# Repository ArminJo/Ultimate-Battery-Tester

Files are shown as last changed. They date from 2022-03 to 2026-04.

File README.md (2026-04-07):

<div align = center>

# Ultimate-Battery-Tester
Program for measuring the ESR (equivalent series resistance) of a battery and printing a graph of the values at discharge.


 &nbsp; &nbsp;

 &nbsp; &nbsp;

 &nbsp; &nbsp;

 &nbsp; &nbsp;

<br/>
<br/>
Stand With Ukraine (https://stand-with-ukraine.pp.ua)

</div>

#### If you find this library useful, please give it a star.

&#x1F30E; [Google Translate](https://translate.google.com/translate?sl=en&u=https://github.com/ArminJo/Ultimate-Battery-Tester)

<br/>

# Table of contents
- [Features](https://github.com/ArminJo/Ultimate-Battery-Tester?tab=readme-ov-file#features)
- [Li-Ion battery capacity](https://github.com/ArminJo/Ultimate-Battery-Tester?tab=readme-ov-file#li-ion-battery-capacity)
- [Battery ESR](https://github.com/ArminJo/Ultimate-Battery-Tester?tab=readme-ov-file#battery-esr)
- [Principle of operation](https://github.com/ArminJo/Ultimate-Battery-Tester?tab=readme-ov-file#principle-of-operation)
- [Measurement of battery packs with external series load resistor](https://github.com/ArminJo/Ultimate-Battery-Tester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)
- [Logger function](https://github.com/ArminJo/Ultimate-Battery-Tester?tab=readme-ov-file#logger-function)
- [Sample screenshots](https://github.com/ArminJo/Ultimate-Battery-Tester?tab=readme-ov-file#sample-screenshots)
- [Sample Arduino 1.89 IDE plots](https://github.com/ArminJo/Ultimate-Battery-Tester?tab=readme-ov-file#sample-arduino-189-ide-plots)
- [Compile with the Arduino IDE](https://github.com/ArminJo/Ultimate-Battery-Tester?tab=readme-ov-file#compile-with-the-arduino-ide)
- [Pictures](https://github.com/ArminJo/Ultimate-Battery-Tester?tab=readme-ov-file#pictures)
- [Schematics](https://github.com/ArminJo/Ultimate-Battery-Tester?tab=readme-ov-file#schematics)
- [Special pin usage](https://github.com/ArminJo/Ultimate-Battery-Tester?tab=readme-ov-file#special-pin-usage)
- [Examples on Wokwi](https://github.com/ArminJo/Ultimate-Battery-Tester?tab=readme-ov-file#examples-on-wokwi)
- [Modes of measurement](https://github.com/ArminJo/Ultimate-Battery-Tester?tab=readme-ov-file#modes-of-measurement)
   * [Mode Setup](https://github.com/ArminJo/Ultimate-Battery-Tester?tab=readme-ov-file#mode-setup)
   * [Stop and Start again](https://github.com/ArminJo/Ultimate-Battery-Tester?tab=readme-ov-file#stop-and-start-again)
   * [Mode DetectingBattery](https://github.com/ArminJo/Ultimate-Battery-Tester?tab=readme-ov-file#mode-detectingbattery)
   * [Mode InitialESRMeasurement](https://github.com/ArminJo/Ultimate-Battery-Tester?tab=readme-ov-file#mode-initialesrmeasurement)
   * [Mode StoreToEEPROM](https://github.com/ArminJo/Ultimate-Battery-Tester?tab=readme-ov-file#mode-storetoeeprom)
   * [Mode Stopped](https://github.com/ArminJo/Ultimate-Battery-Tester?tab=readme-ov-file#mode-stopped)
   * [Cutoff display](https://github.com/ArminJo/Ultimate-Battery-Tester?tab=readme-ov-file#cutoff-display)
- [Revision History](https://github.com/ArminJo/Ultimate-Battery-Tester?tab=readme-ov-file#revision-history)

<br/>

# Features
- **Measurement of the ESR (equivalent series resistance) of the battery.** This is an indicator of the health of the battery.
- **Storing of voltage, current and ESR graph for up to 22 hours as well as capacity in EEPROM** while discharging.
- The **stored and displayed voltage is the "no load" voltage**, and is therefore **independent of the ESR**, as is the capacity.
- Current measurement values or complete EEPROM stored measurement graph can be displayed with **Arduino Plotter**.
- Easy **continuing of interrupted discharge measurements**.
- Display of ESR, voltage, current and capacity on a **1602 LCD**.
- Display of values and the **discharge graph on a tablet or mobile** running the [BlueDisplay](https://play.google.com/store/apps/details?id=de.joachimsmeyer.android.bluedisplay) app.
- Computing of **"Standard" capacity** between NominalFullVoltageMillivolt and SwitchOffVoltageMillivoltHigh to enable better comparison of capacity measurements.
- Selectable cutoff voltage `Standard`, `Low` and `Zero` (for research). E.g. for Li-ion they are 4.3 V, 3.0 V and 0.18 V.
- Support of **2 different load resistors** for different battery voltages to keep current below 600 mA.
- Support of **4 automatically selected voltage ranges** 2.2 V, 4.4 V, 17.6 V and 64.9 V. This results in a high resolution ranging from 2.1 mV to 63 mV.
- Support of **external series load resistor** e.g. for measuring of battery packs.
- **Logger mode (voltage + current)** for charting external charger or similar devices.
- In case the ESR is changing a lot, the **load voltage** can be determined by looking at the current, because the load resistance is constant.

<br/>

# Li-Ion battery capacity
For Li-Ion the capacity is specified for discharge from **4.2 V to 3.0 V** as in [CGR18650CG Datasheet](https://github.com/ArminJo/Ultimate-Battery-Tester/blob/master/CGR18650CG-Panasonic.pdf)
or to **2.75 V** as in [ICR18650-26A Datasheet](https://github.com/ArminJo/Ultimate-Battery-Tester/blob/master/ICR18650-26A_Samsung.pdf) or even to **2.5 V**.<br/>
The **UltimateBatteryTester has a cut-off voltage of 3.4 V** for Li-Ion to treat the cells with care.<br/>
This results in a reduced capacity displayed by approximately the factor 0.85 (1.18), e.g. a Li-Ion cell with nominal capacity of 2150 mAh at 3 V EOD (End Of Discharge) is measured as 1830 mAh at 3.5 V EOD.<br/>
The cut off voltage can be changed to low values by connecting pin 11 to ground. See [here](https://github.com/ArminJo/Ultimate-Battery-Tester?tab=readme-ov-file#special-pin-usage).

<br/>

# Battery ESR
The internal resistance is an indicator of the health of the cell. E.g. if a NiMH cell has an ESR of **1 &ohm;**, it delivers **only 1 volt at a current of 200 mA** instead of 1.2 V, which may be to low for the circuit to work properly.<br/>
ESR values for NiMH can go down to excellent 0.05 &ohm;.<br/>
Typical ESR value for a 18650 Li-Ion cell is 0.05 &ohm;.

It seems that the **dynamic ESR** measured by devices like **YR1035+** is around half as much as the **static ESR** measured by this program.
This was suprising for me, since I expected only a fixed offset, because of connection imperfections.<br/>
But this **static ESR gives you a better impression of the voltage loss at a given static current**.

<br/>

# Principle of operation
The battery type is detected by a fixed mapping of voltage to type in `BatteryTypeInfoArray[]`.
While the Mosfet is switched on, the voltage at the 2 &ohm; shunt resistor is measured to get the current. The voltage at the battery terminal is measured to get the voltage under load.<br/>
Every second, the Mosfet is deactivated for 10 ms or 100 ms (depending on battery type), the "no load" voltage at the battery terminal is measured and the Mosfet is switched on again.<br/>
The formula for ESR is: **(noLoadVoltage - loadVoltage) / loadCurrent**.<br/>
Please keep in mind, that the **maximum current which can be measured with the 2 &ohm; shunt resistor is 545 mA**.<br/>
The internal LED is active for the time the load is detached. This results in a 1 second blinking.

Every minute, current data is stored/appended to EEPROM. **The complete data is printed in Arduino Plotter format at each reboot**.
So it is possible to interrupt the measurement or switch it off after the measurement is finished, without loosing data.
More details can be found [below](https://github.com/ArminJo/Ultimate-Battery-Tester?tab=readme-ov-file#modes-of-measurement).

If `#define SUPPORT_BLUEDISPLAY_CHART` is activated, values and the discharge graph are printed on a tablet or mobile running the [BlueDisplay](https://play.google.com/store/apps/details?id=de.joachimsmeyer.android.bluedisplay) app.<br/>
The new version of the app also supports a USB OTG connection. This eliminates the need for an additional Bluetooth module.

<br/>

# Measurement of battery packs with external series load resistor
Battery packs up to 64.9 volt (15s) can also be measured.
**However, it is important to keep the current below 545 mA**, as this is the maximum allowed for current measurement with the 2 &ohm; shunt resistor.<br/>
This can be achieved by **adding an extra resistor in series with the built-in 12 &ohm; resistor**.<br/>
The voltage must still be measured directly at the battery terminal.
For this I use a distinct cable for voltage measurement, connected to the battery’s positive lead.<br/>
No further modifications are required.

<br/>

# Logger function
Connecting pin 10 to ground enables Logger mode after startup. In this mode, voltage is measured at the same pin used for Battery mode.
For current measurement, Logger mode uses a separate external shunt connected to pin A4.<br/>
To minimize interference with the circuit under test, this shunt is typically smaller than the one used in Battery mode. 
Its resistance is defined by `LOGGER_SHUNT_RESISTOR_MILLIOHM` (e.g., 200 for 0.2 &ohm;).<br/>
The measurement stops when the current falls below a specified fraction of the initial current. 
Available thresholds are 50%, 25%, or 12.5%, with 12.5% as the default. 
This default is particularly useful for logging charging circuits that gradually reduce current toward the end of the charge cycle.

<br/>

# Sample screenshots
This screenshots are from an 1200x800 tablet running the [BlueDisplay](https://github.com/ArminJo/Arduino-BlueDisplay) app.
The Arduino is connected to the tablet via **OSB OTG** or a **Bluetooth module** like HC-05, see [here](https://github.com/ArminJo/Arduino-BlueDisplay?tab=readme-ov-file#bluedisplayblink).

|  |  |
|-|-|
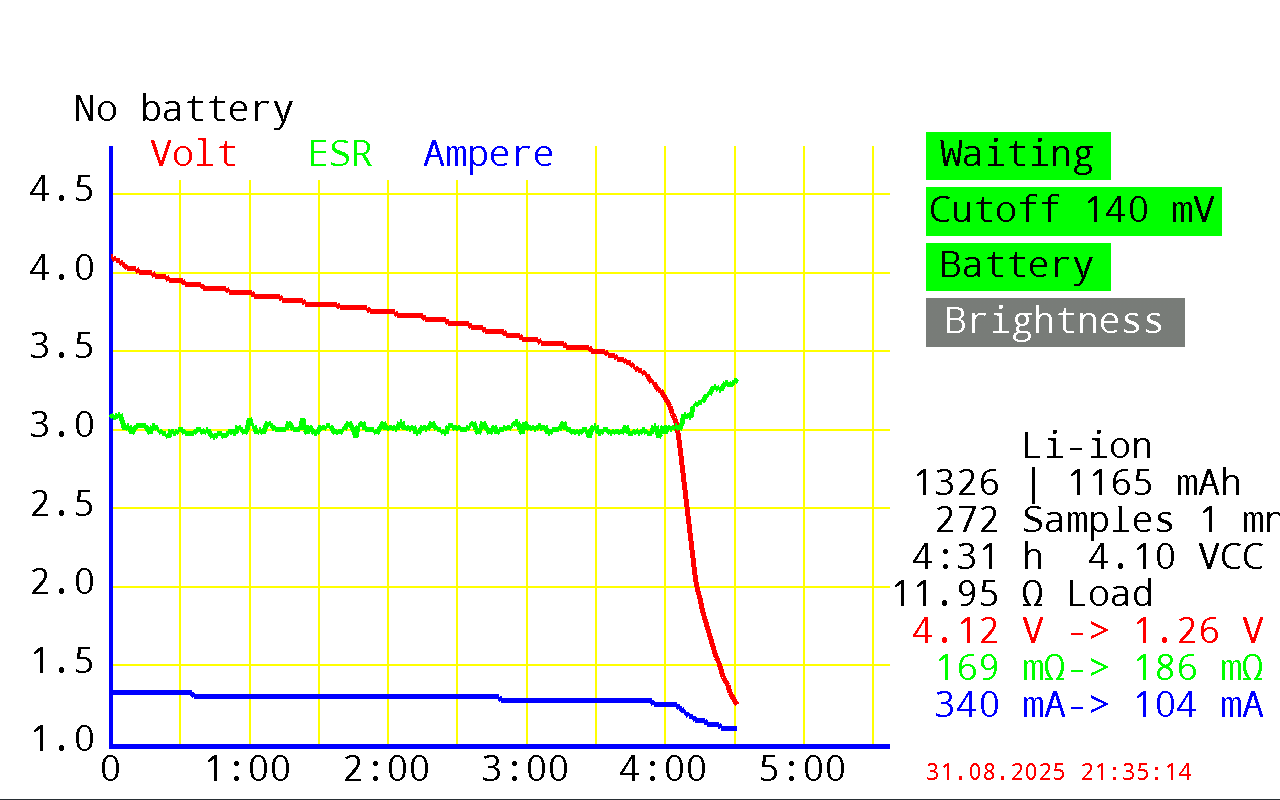
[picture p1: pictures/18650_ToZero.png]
Li-ion
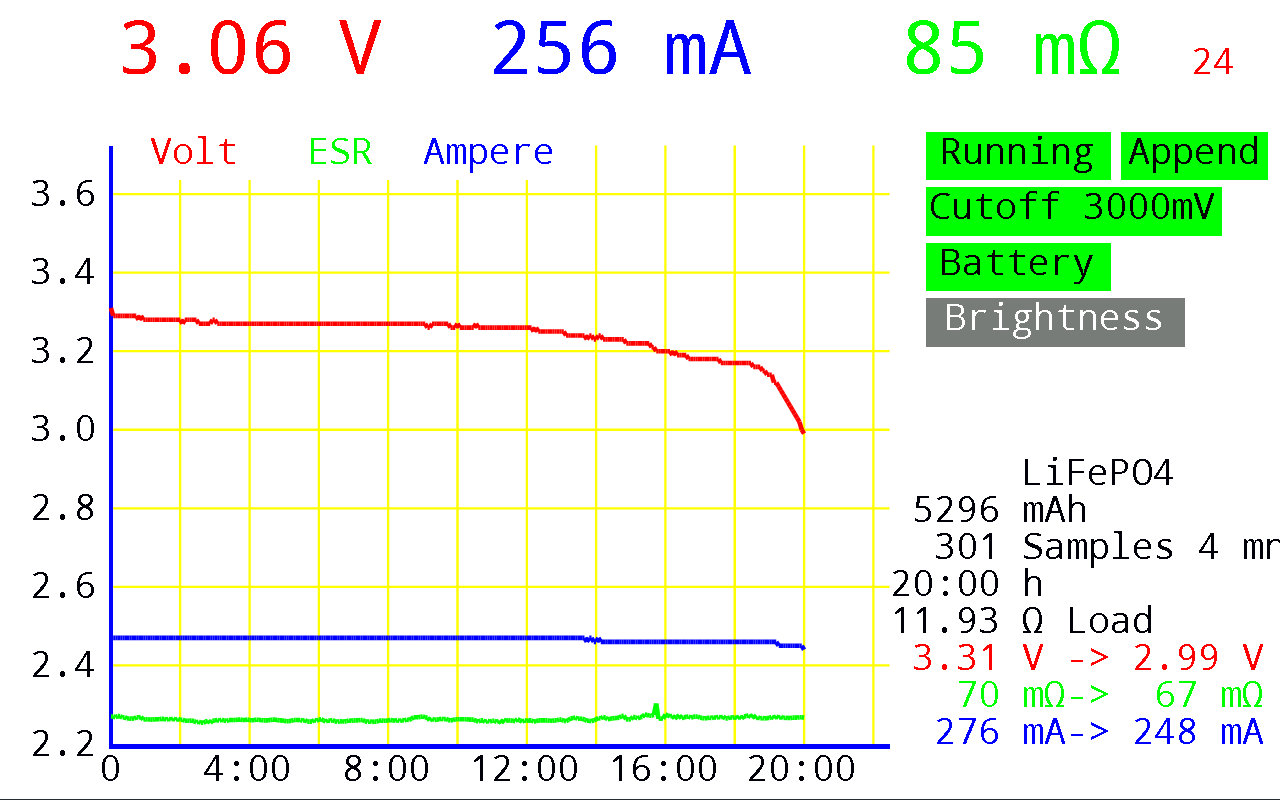
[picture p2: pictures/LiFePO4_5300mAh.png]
LiFePO4_5300mAh
|  |  |
| Used 18650 Li-ion battery. | LiFePO4 battery with 5300 mAh.  |
| | |
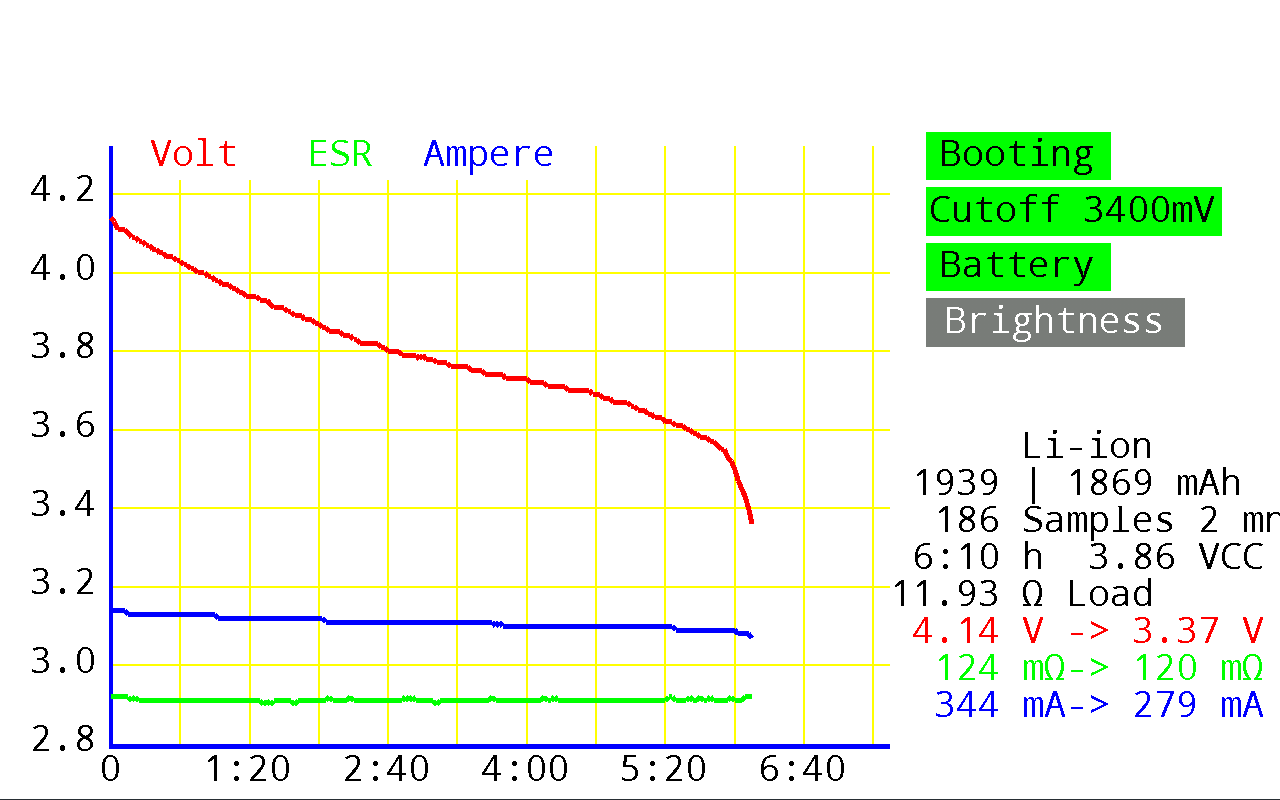
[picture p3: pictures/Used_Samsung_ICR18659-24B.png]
Used_Samsung_ICR18659-24B
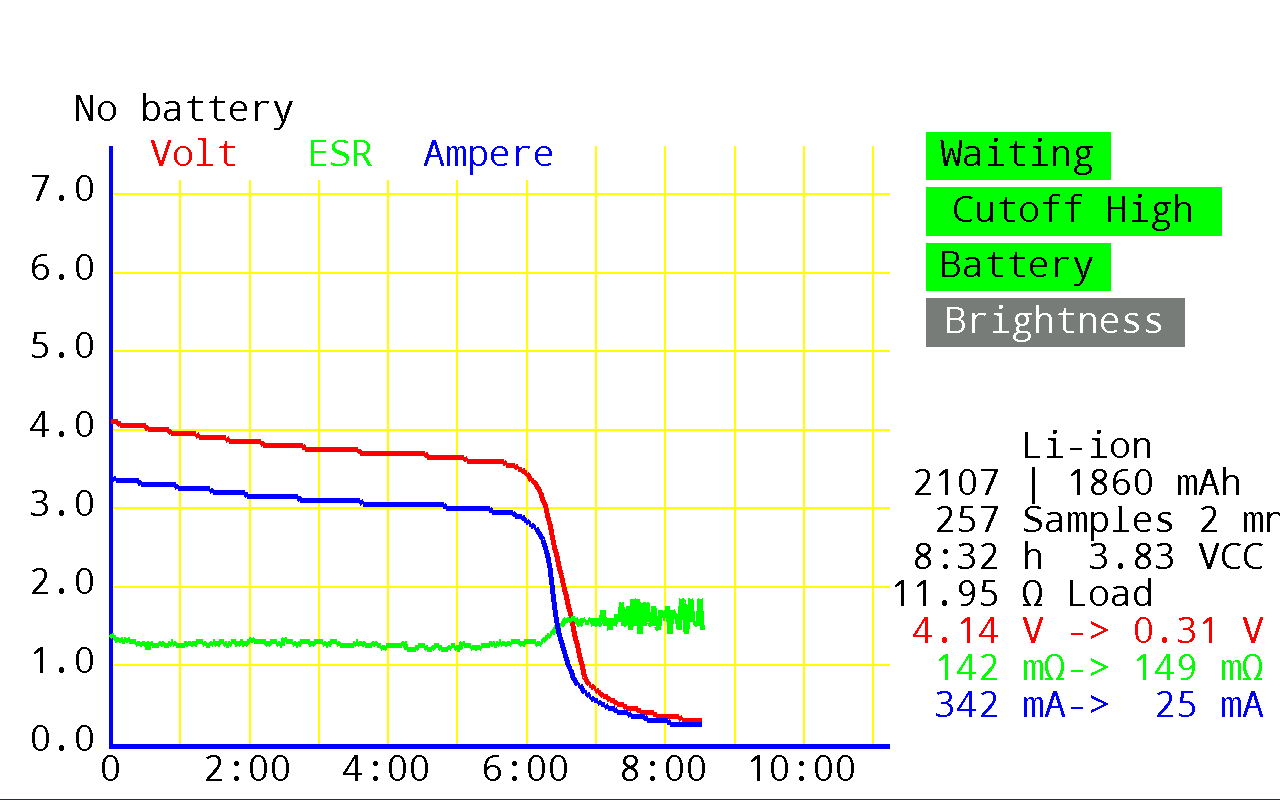
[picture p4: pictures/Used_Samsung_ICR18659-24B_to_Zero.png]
Used_Samsung_ICR18659-24B_to_Zero
|  |  |
| Used Samsung ICR18659 24B with 1100 mAh. | The same Samsung ICR18659 24B **accidentally discharged to almost zero**. Here you can see the small capacity below 3.4 V. After directly recharging with 10 mA until 2.8 V and then with 30 mA to 3.5 V the capacity and ESR were like before, which I did not expect :-). |
| | |
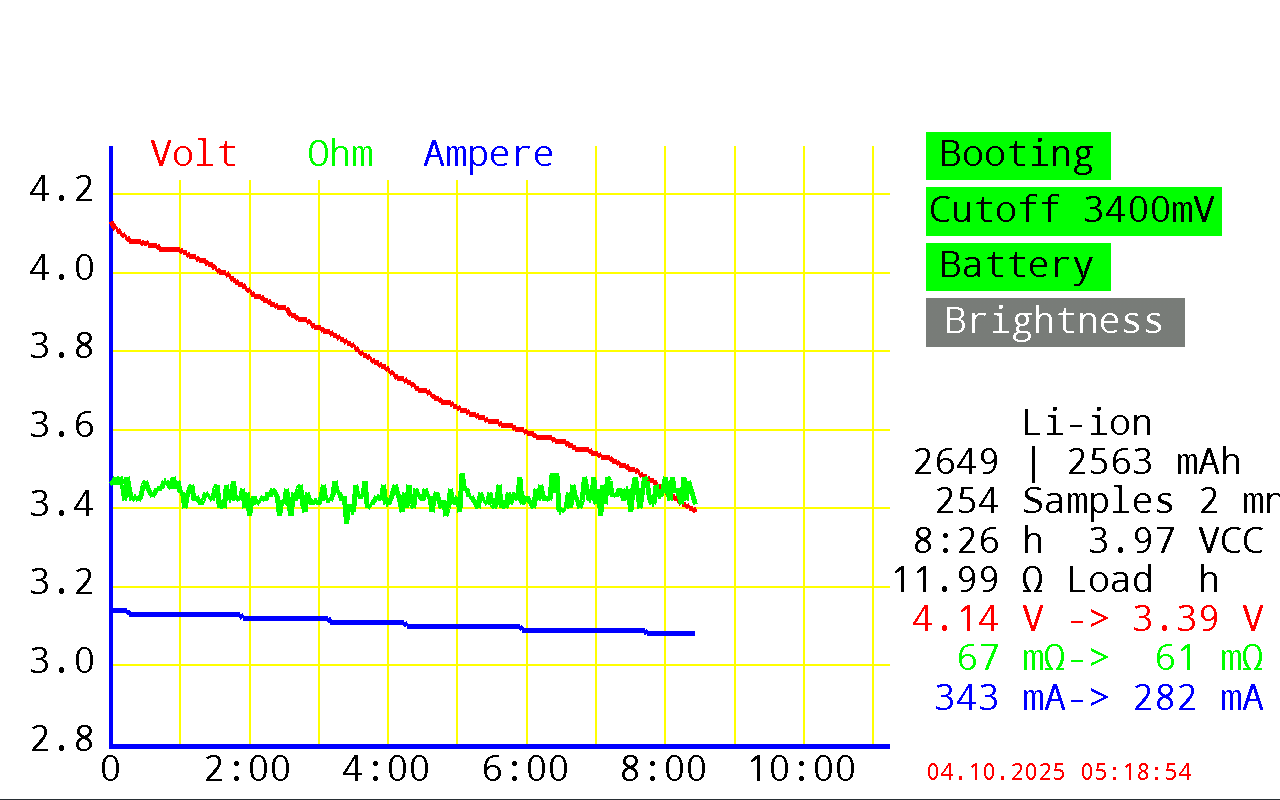
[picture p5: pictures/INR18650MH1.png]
INR18650MH1
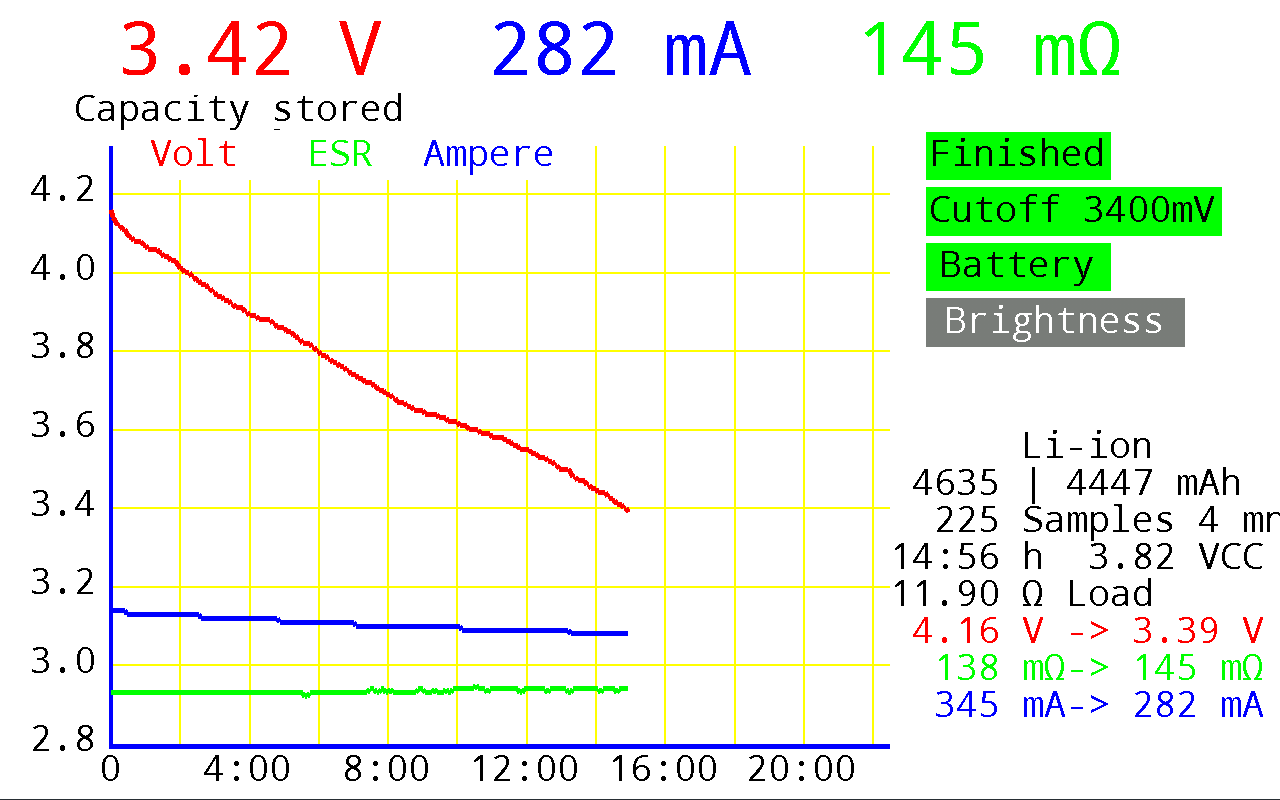
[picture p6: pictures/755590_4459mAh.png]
755590_4459mAh
|  |  |
| A LG INR18650MH1 cell salvaged from a scooter battery. |  A new 755590 pouch cell with 4459mAh and an ESR of 0.14 &ohm;, maybe because of the protection circuit. |
| | |
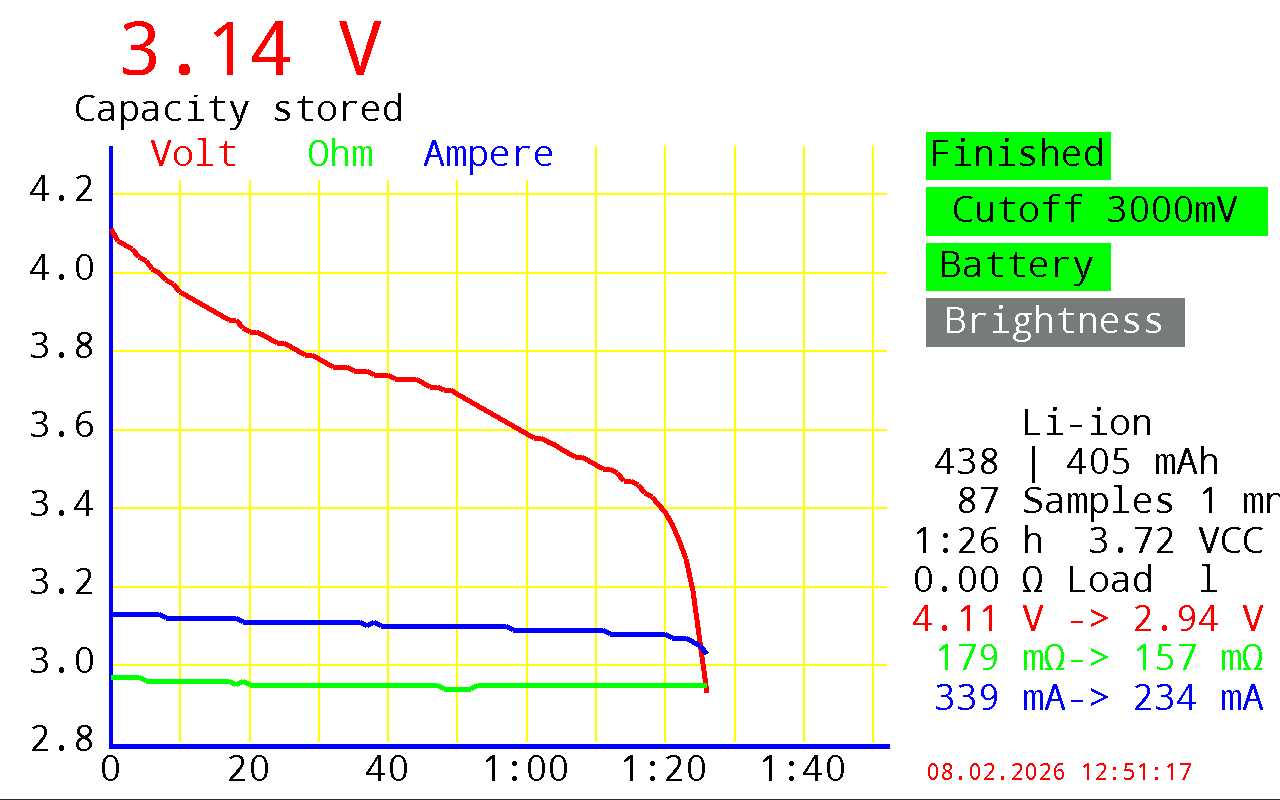
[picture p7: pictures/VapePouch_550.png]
VapePouch
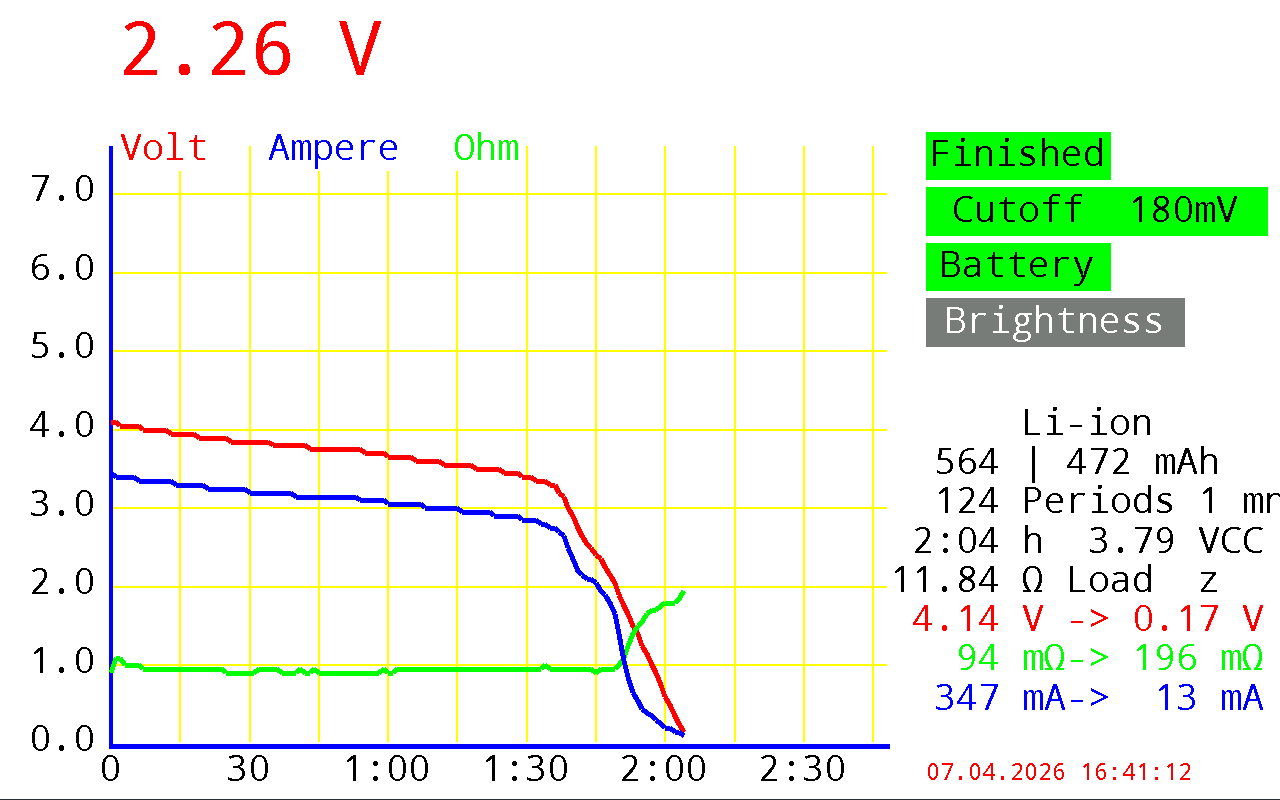
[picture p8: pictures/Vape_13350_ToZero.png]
VapeRound
|  |  |
| A 550 mAh pouch cell salvaged from a vape. | A 13350  450 mAh? cell salvaged from a vape. |
| | |
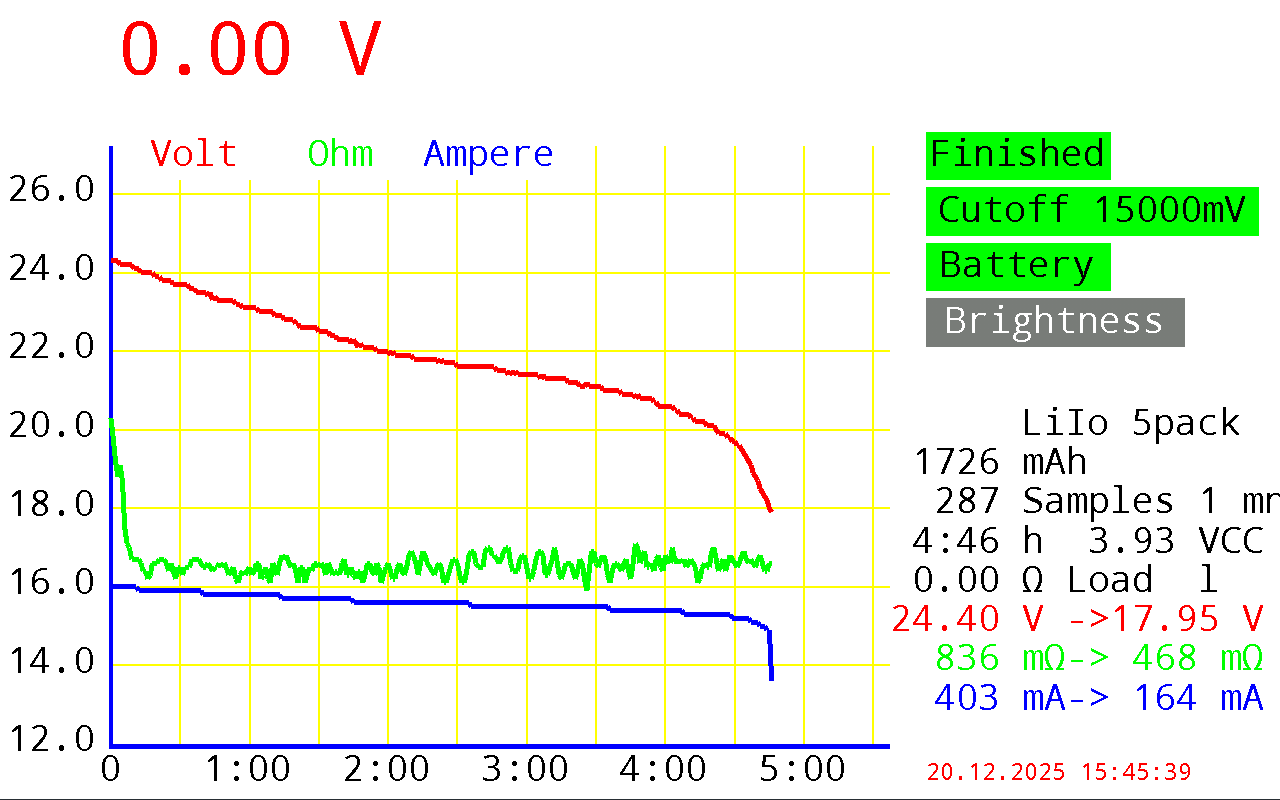
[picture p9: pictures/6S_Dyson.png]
Dyson pack
|  | |
| A 6s Dyson battery pack. | |

<br/>

# Sample Arduino 1.89 IDE plots
The plots are created with the Arduino 1.x Serial Plotter. The Arduino 2.x Serial Plotter is not as powerful and uses a different data format.

Plot for **2 parallel 18660 Li-Ion cells**.<br/>
The first capacity value is the "standard" capacity measured from the first peak at standard full voltage 4100 mV to the second peak, the cutoff "high" voltage at 3400 mV.<br/>
The peaks, which are 50 mV added to the measured value, are artificially generated for easy recognition of the capacity range.<br/>
The second peak is always suppressed for graphs with discharge to "high", because the end of this graph is by definition the end of the standard capacity range.<br/>
The second capacity value is the total capacity measured in this graph.<br/>
**The displayed voltage is the "no load" voltage**, to be independent of the current load resistor.
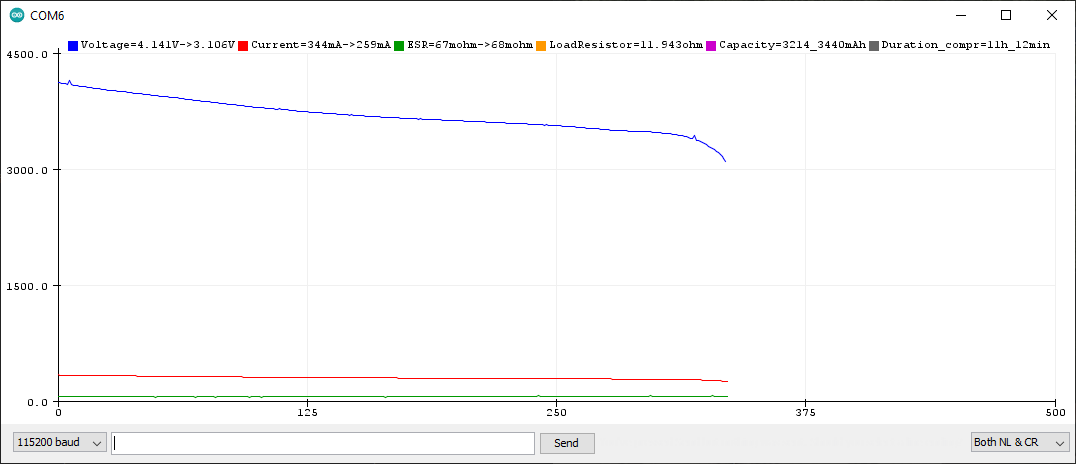
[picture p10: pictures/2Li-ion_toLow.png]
2Li-ion_toLow


Plot a **worn out single Li-ion cell** with increased ESR and a more flat curve at 3.4 V.
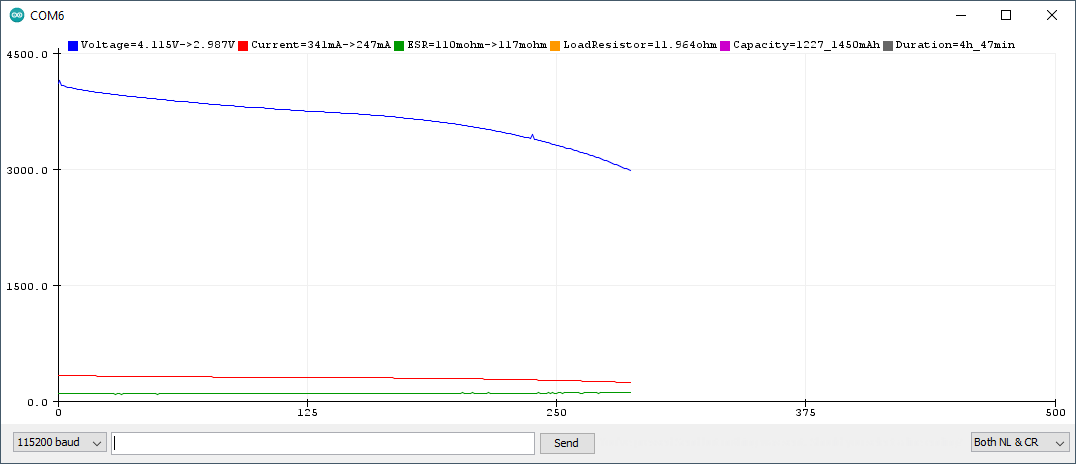
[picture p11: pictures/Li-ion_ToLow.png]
Li-ion_toLow


Plot for a **NiMH cell** with 55 m&ohm; ESR.
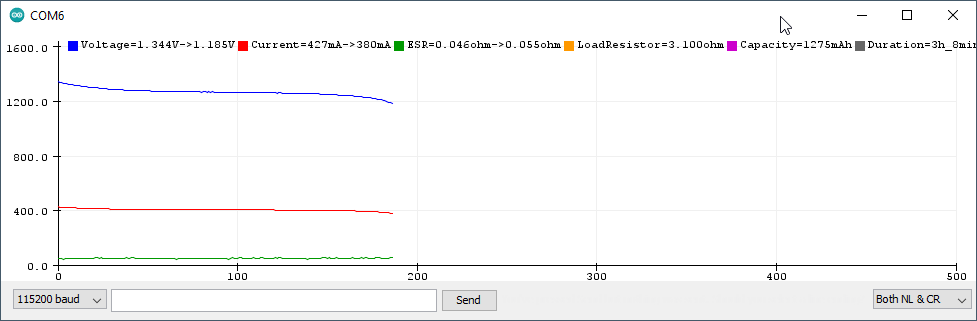
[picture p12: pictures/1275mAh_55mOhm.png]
870mAh_120mOhm


Plot of a NiMh battery sold as 4/5AA 1800mAh Ni-Mh showing only 960 mAh.
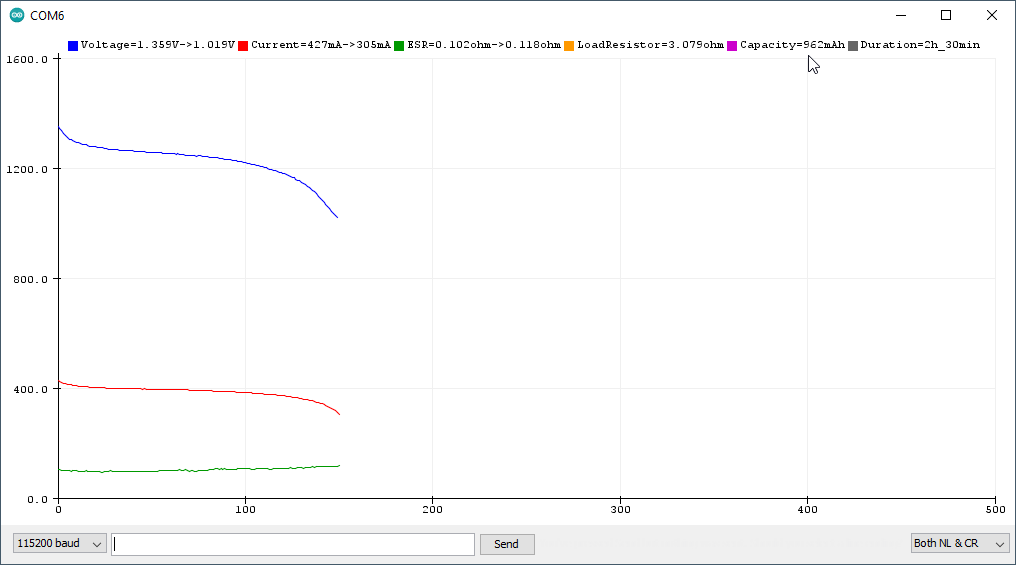
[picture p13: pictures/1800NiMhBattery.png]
1800mAh
 

<br/>

# Compile with the Arduino IDE
Download and extract the repository. In the Arduino IDE open the sketch with File -> Open... and select the UltimateBatteryTester folder.

As the program size is at around 100%, you need to burn the UNO bootloader on the Nano before loading the program onto the Nano.

# Pictures

| Overview with distinct voltage measurement cable (thin red one) to enable additional series resistors for battery packs | Top View |
|-|-|
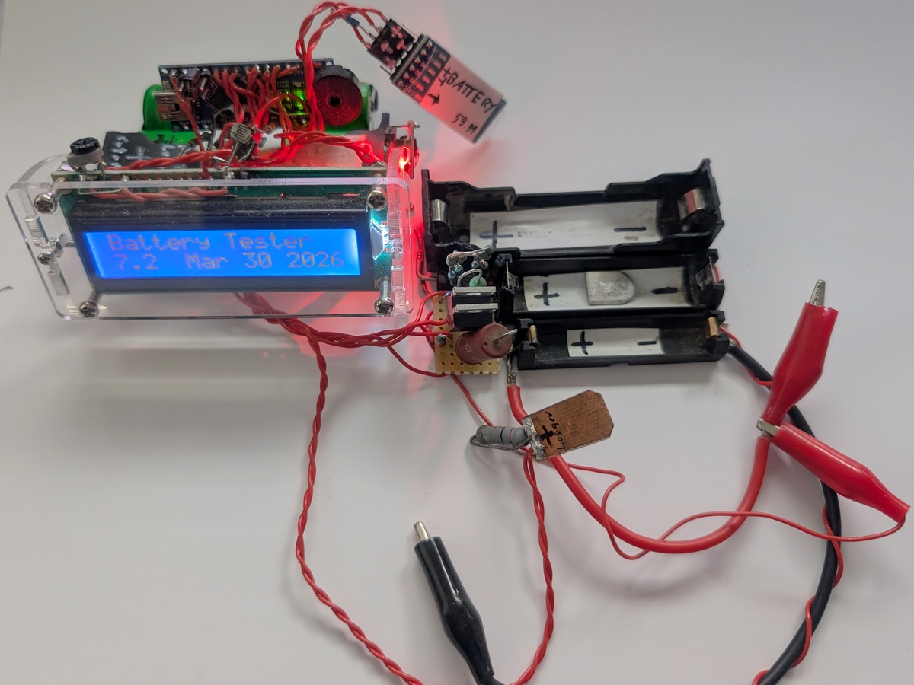
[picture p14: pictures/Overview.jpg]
Overview
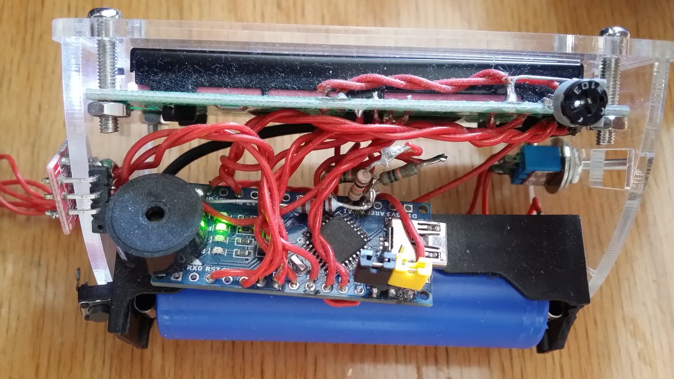
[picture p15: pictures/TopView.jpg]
Top View
|  |  |
| Battery holder top view  | Reset and application sensor button |
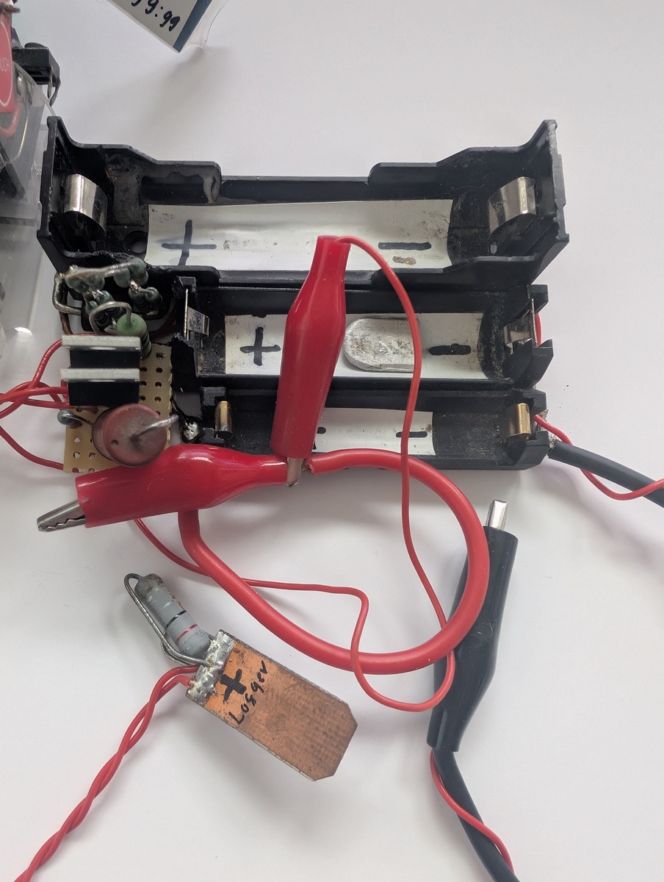
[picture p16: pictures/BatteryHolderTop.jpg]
BatteryHolderTop
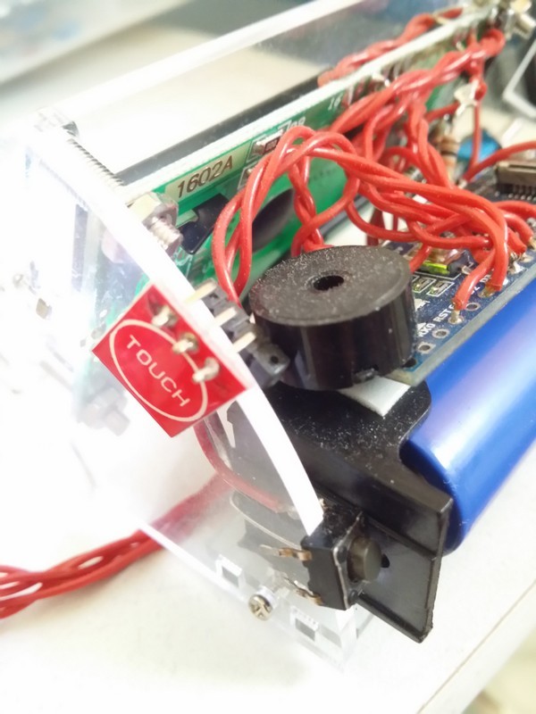
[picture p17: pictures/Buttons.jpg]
Reset and application sensor button
|  |  |
| Battery holder bottom view | MosFets |
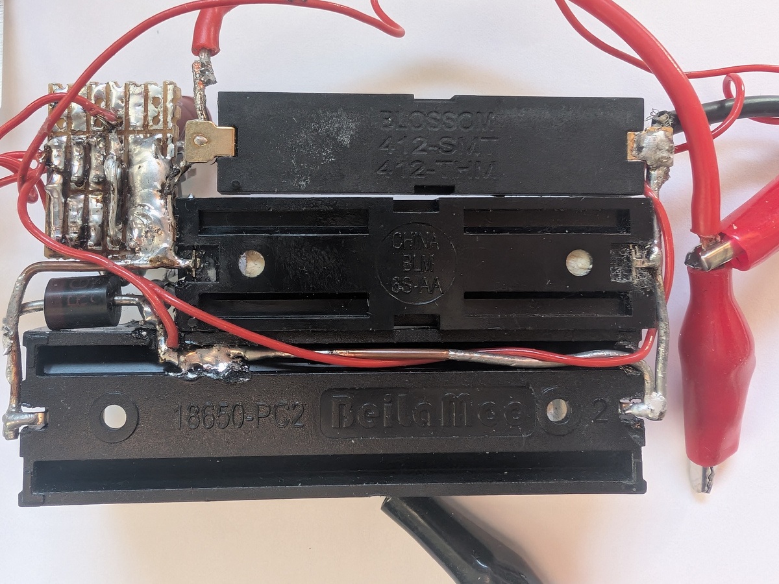
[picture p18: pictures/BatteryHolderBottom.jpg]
Battery holder bottom view
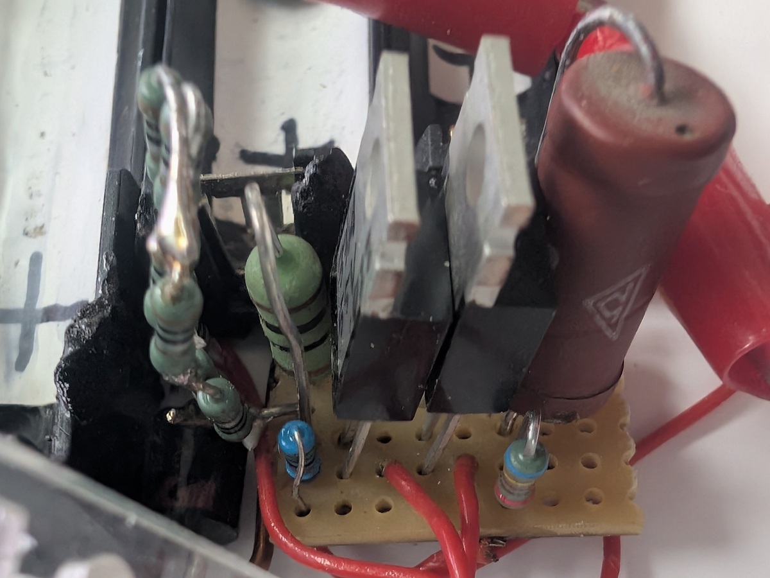
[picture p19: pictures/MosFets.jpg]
|  |  |

# Schematics
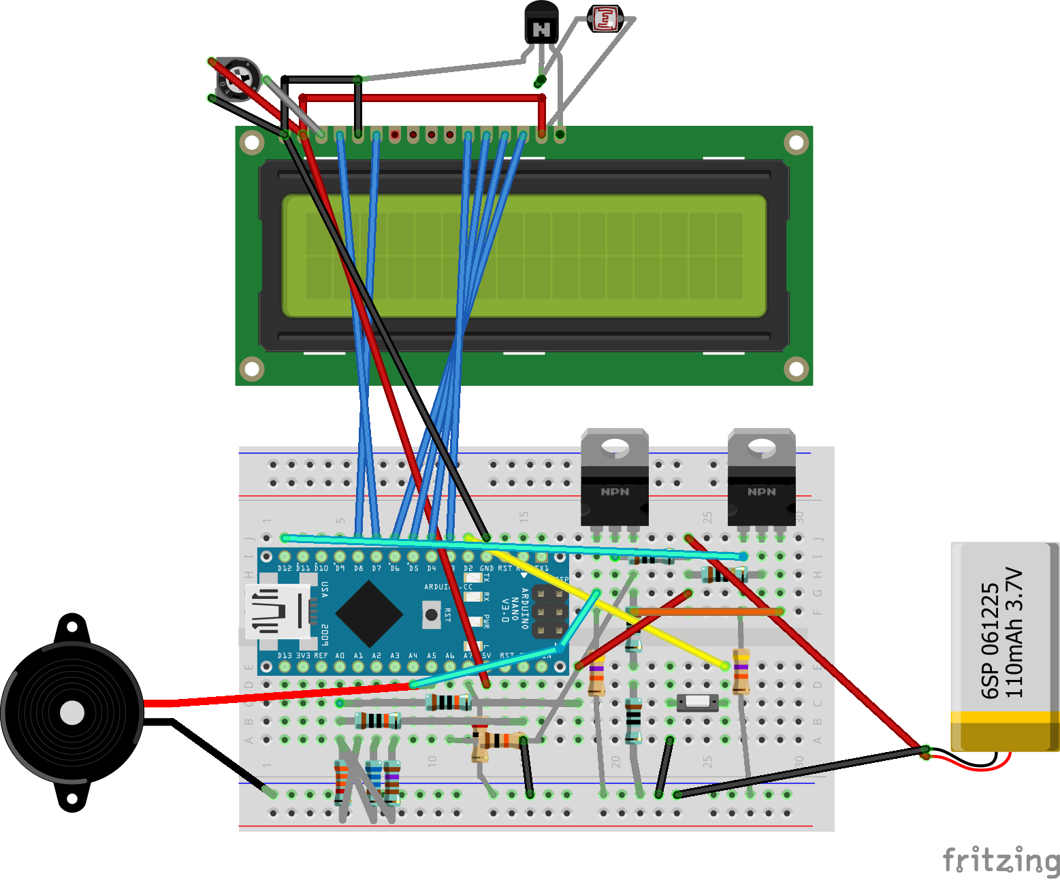
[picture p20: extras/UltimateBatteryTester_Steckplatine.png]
Fritzing board

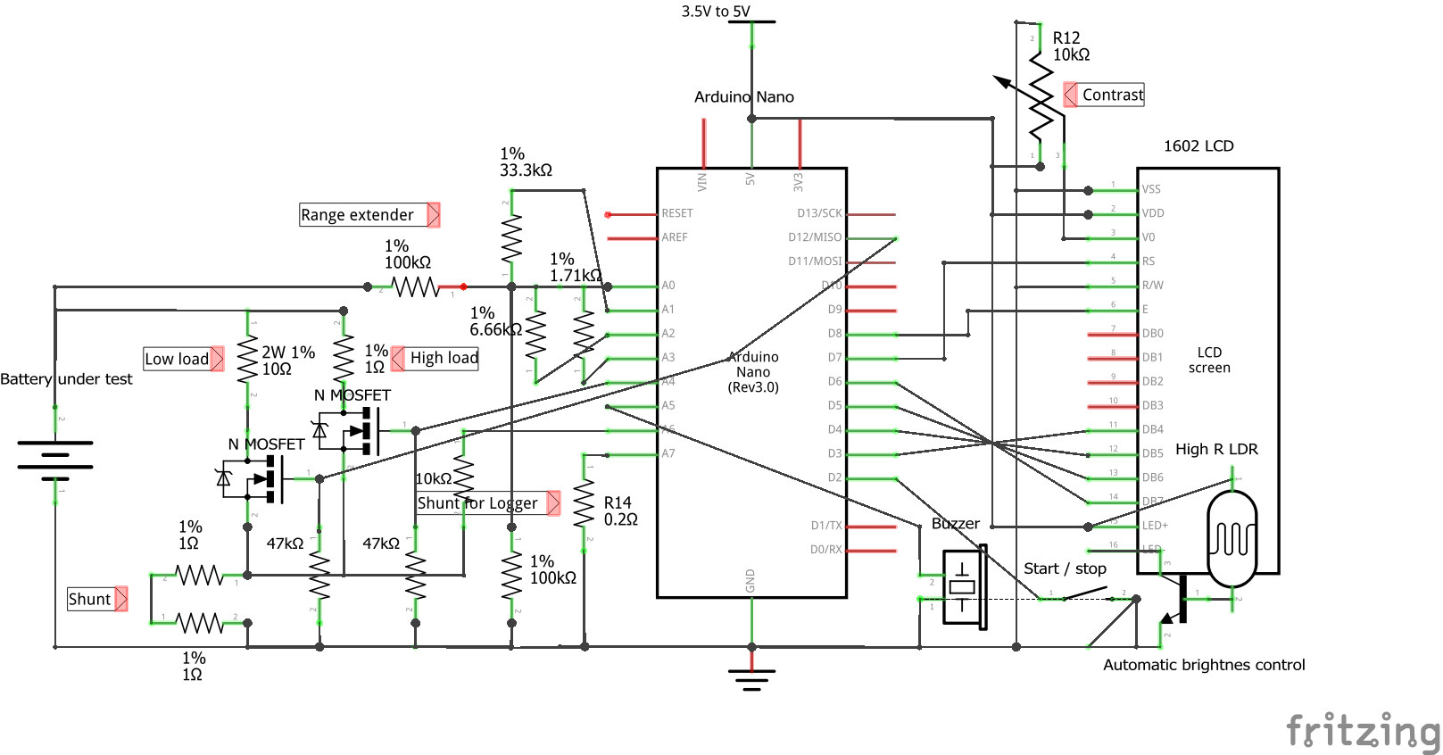
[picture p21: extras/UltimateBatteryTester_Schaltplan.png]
Fritzing schematics


# Special pin usage
If **pin 9** is connected to ground, verbose output for Arduino Serial Monitor is disabled. This verbose output is not suitable for Arduino Plotter.<br/>
If **pin 10** is connected to ground, **logger mode** is entered. I.e. current is measured at the shunt at channel 4 / A4 and voltage still at channel 0 / pin A0.<br/>
If **pin 11** is connected to ground, `CUTOFF_LEVEL_LOW` is taken as startup default if no battery is inserted at startup, "cut off is low" is displayed and discharge ends at a lower voltage. E.g. Li-ion discharge ends at 3000 mV instead of 3500 mV.

# Examples on Wokwi
The screenshots below are taken from this [Wokwi example](https://wokwi.com/projects/381051341790948353).

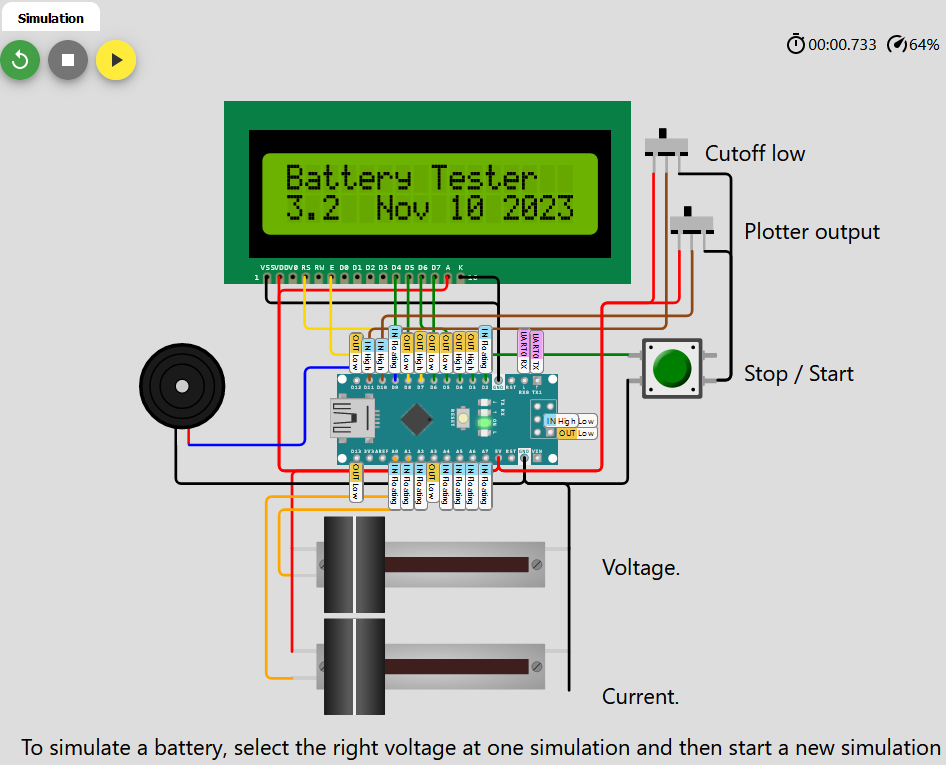
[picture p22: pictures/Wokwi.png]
Wokwi


# Modes of measurement
After reset the tester starts with mode Setup:

## Mode Setup
After boot, the tester displays its name and version and date for 2 seconds.

BatteryTester

The message `No plotter out` is displayed in the second row for 2 seconds.
If pin `PIN_ONLY_PLOTTER_OUTPUT` (pin 10) is held low, then the message `Only plotter out` is displayed.

NoPlotterOut
OnlyPlotterOut

Then it prints the data read from EEPROM to serial monitor and displays ESR and capacity.
The Arduino supply voltage (VCC) together with the message `Stored data` is displayed in the first row for 2 seconds.<br/>
The character `h` or `l` or `z` shows the cutoff voltage of the stored data.

StoredData

Then the message `cutoff high` or `low`  and the cutoff voltage is displayed in the first row for 2 seconds.<br/>
If battery is still inserted, it reflects the cutoff voltage of the stored data, to enable easy **continuing an interrupted measurement**.<br/>
If no battery is inserted, this cutoff message reflects the state of the pin `PIN_DISCHARGE_TO_LOW`.

CutoffHigh
CutoffLow

After this, **mode is switched to DetectingBattery**.<br/>

## Stop and Start again
A double press during 0.4 seconds always displays `Stop measurement` for 2 seconds and then **mode is switched to Stopped**.<br/>
Another press will start again.
`Stopped B` means stopped by **button** press, `Stopped D` means stopped by button **double** press, `Stopped F` means stopped by EEPROM **full**,
`Stopped -` means stopped by reaching the cutoff voltage and `Stopped U` means stopped by VCC undervoltage.

StopMeasurement
Stopped

StartAgain

## Mode DetectingBattery
If no battery is inserted, the Arduino supply voltage (VCC) together with the message `No batt.` is displayed in the first row until a battery is inserted.<br/>

NoBatt

By pressing the stop button, you can toggle cutoff voltage between high, low and zero (50 mV).

NoBatt
NoBatt
NoBatt

If a battery is inserted, you see e.g.

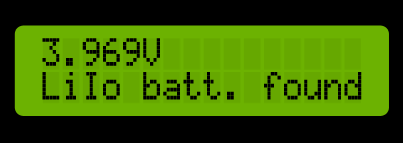
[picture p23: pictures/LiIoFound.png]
LiIoFound


for 2 seconds.
Then the messages `dbl press = stop`,  and `Press button to append to EEPROM` are displayed for 2 seconds each, but only once after boot.

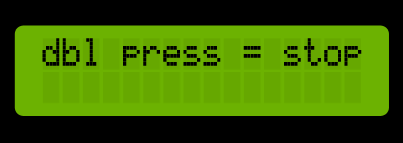
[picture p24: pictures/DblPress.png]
DblPress

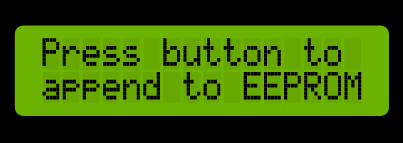
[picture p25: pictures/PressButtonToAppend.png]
PressButtonToAppend


After this, the mode is **switched to InitialESRMeasurement**.

## Mode InitialESRMeasurement
This mode lasts for 30 seconds before a new measurement is initiated and **mode is switched StoreToEEPROM**.<br/>
This 30 seconds can be used to quick check a battery, without overwriting the already stores values.<br/>
A button press during the 30 seconds **switches directly to mode StoreToEEPROM and appends to already stored EEPROM data**, instead of starting a new measurement.
This enables it to connect the tester to the Arduino Serial Plotter at any time in the measurement without loosing data already acquired.
Because connecting to the Serial Plotter always resets the tester, we must be able to avoid to start a fresh measurement after reset.

InitialESRMeasurement

In the first row the **no load voltage** of the battery, the **30 second countdown** and the **load current** is displayed.
In the second row the **ESR** and the **difference between the load and no load voltage**, used to compute the ESR, is displayed.<br/>
A value of **99.999 &ohm; indicates overflow** over the maximum value of 65.535 &ohm;.

## Mode StoreToEEPROM
- Every second, a sample is taken and displayed.
- Every 60 seconds the sample is stored.
- For the first 337 samples (5:37 hours) each 8 bit delta is stored to EEPROM.
- After 337 samples, all data are compressed by combining 2 samples and doubling the sample period This can be done multiple times.
- The number between the voltage and the current in the first row is the storage minute count and incremented at each storage.

Storing

If the **no load voltage drops below the cut off voltage** or the start/stop button is pressed, `Capacity stored` is displayed for 2 seconds,
the current capacity is written to EEPROM and **mode is switched to Stopped**.

CapacityStored

## Mode Stopped
The battery no load voltage is displayed in the first row. A stop melody is played and `Finished` is displayed **after reaching the cutoff voltage**.<br/>
`Stopped B` is displayed after manual stopping by button press.<br/>

Finished
Stopped by button single press

After another button press `Start again` is displayed and **mode is switched to DetectingBattery**.
StartAgain

## Cutoff display
If the state of the `PIN_DISCHARGE_TO_LOW` pin changes, the message `cutoff high` or `low`
and the according cutoff voltage is displayed in the first row for 2 seconds.

CutoffHigh
CutoffLow

# Revision History
### Version 7.2.0
- BatteryTypeInfoArray now in FLASH memory.

### Version 7.1.0
- Fixed bugs in ESR and load resistor computations.
- Fixed overflow bug relevant after 336 storage periods.
- Use period instead of sample for display.

### Version 7.0.0
- Changed analog pin assignments for two additional voltage ranges using internal reference.
- Fixed some bugs in logger mode.
- First tap on Brightness button only makes refresh.

### Version 6.0.0
- Improved logger handling.
- Improved chart scaling.
- Display of date and time for BlueDisplay mode. This requires 1304 bytes program memory and does not work for plain Arduino, because the "-mrelax" linker option is not set.
- Refactoring.
- Added battery specific zero value.

### Version 5.1.0
- Adaptive Chart data text size.
- Improved RunningState BDButton handling.

### Version 5.0.0
- Compression is now done by simply doubling the sampling period, which results in reducing the resolution from 336 of 168 samples directly after compression.
- Data and chart can be displayed on (old) tablets or mobile running the BlueDisplay app https://github.com/ArminJo/Arduino-BlueDisplay.
- Plotter pin logic does not depend any more on USB powering.
- Tested logger function with chart.

### Version 4.0.0
- Use capacity between NominalFullVoltageMillivolt and SwitchOffVoltageMillivoltHigh as standard capacity to enable better comparison.
- If powered by USB plotter pin logic is reversed, i.e. plotter output is enabled if NOT connected to ground.
- In state detecting battery, you can toggle cutoff voltage between high, low and zero (50 mV) with stop button.
- Fix bug for appending to compressed data.
- Support for storage period of 120 s.
- Synchronizing of LCD access for button handler, avoiding corrupted display content.
- Print improvements.
- Support for storage period of 120 s.
- Compression improved for rapidly descending voltage.
- Moving seldom used function of pin 10 to pin A5.
- New Logger mode with separate shunt enabled by pin 10.
- Store data in an array of structure instead in 3 arrays

### Version 3.2.1
- BUTTON_IS_ACTIVE_HIGH is not default any more

### Version 3.2.0
- Cutoff message improved.

### Version 3.1.0
- Fixed "conversion does not clear rest of EEPROM" bug.

### Version 3.0.0
- Improved compression.
- Attention by short beep each minute in STATE_DETECTING_BATTERY.

### Version 2.2.0
- ESR > 64 bug fixed.
- Display of changes on pin PIN_DISCHARGE_TO_LOW.

### Version 2.1.0
- ESR is stored and not computed any more.

### Version 2.0.0
- Improved version.

### Version 1.0.0
- Initial version with EEPROM storage.

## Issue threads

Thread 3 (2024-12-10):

Questions to build your project

DarkShadowNight, 2024-12-10:
Hello,

I like your project, Yet I am not able to replicate.
Some general remarks, questions:

- ADC_INTERNAL_REFERENCE_MILLIVOLT: Might need to explain how to measure to some less advanced users.
- ADC_CHANNEL_VOLTAGE: Watch out it's channel and not pin numbers, took me quite some time to figure out!
- ADC_CHANNEL_CURRENT / ADC_CHANNEL_LOGGER_CURRENT: What is the difference, I don't understand.
- Why is the internal LED flashing (pin 13), Timer running for PWM buzzer?
- ONLY_LOGGER_MODE_PIN: How it's measured when not connected to ground?
- LOGGER_SHUNT_RESISTOR_MILLIOHM : How, why, when?
- #define USE_PARALLEL_LCD //#define USE_SERIAL_LCD: Is this a nice way to switchover to I2C to comment and uncomment here?
#define ONLY_PLOTTER_OUTPUT_PIN and #define ADC_CHANNEL_LOGGER_CURRENT is a disaster it suddenly redeclarates if you think you have done your declarations already.
- #define LCD_COLUMNS 16 and #define LCD_ROWS 2: Not friendly on 20 * 4 display for erasing additional characters correctly.

Thanks

ArminJo, 2024-12-11:
Hi, thanks for the feedback 👍 .
I tried to document most of your concerns, maybe you can check again and update your feedback.
Logger functionality is not yet properly tested...

DarkShadowNight, 2024-12-12:
It is working now, thanks!
Why not include softwareserial for debugging / tracing?

https://github.com/salaiaungmyintmyat/OnePinOnly_SoftwareSerial

ArminJo, 2024-12-12:
> Why not include softwareserial for debugging / tracing?

The standard serial is available for this, so why do you ask?

DarkShadowNight, 2024-12-14:
Might be easy to have the debug output and trace output on a separate pin
Going to try to change your code to use this plotter, could be a nice alternative for the Arduino plotter:
https://hackaday.io/project/181686-better-serial-plotter/details

Closed 2024-12-12.

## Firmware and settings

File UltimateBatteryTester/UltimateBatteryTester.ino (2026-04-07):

/*
 *  UltimateBatteryTester.cpp
 *
 *  Measure Voltage, current, ESR (internal series resistance) and capacity of batteries.
 *  Stores the values in EEPROM and display the values and the discharge graph on a tablet or mobile
 *  running the BlueDisplay app https://play.google.com/store/apps/details?id=de.joachimsmeyer.android.bluedisplay
 *  or on a connected Arduino Plotter.
 *
 *  The load is periodically detached to compute the ESR of the battery.
 *  ESR is: (noLoadVoltage - loadVoltage) / loadCurrent.
 *  The internal LED is active for the time the load is detached. This results in a 1 second blinking.
 *
 *  To suspend a measurement while in storage mode, press single for stopping and storing current capacity.
 *  If measurement is stopped, it can be started by another press and then the new measurement must be appended by another press.
 *
 *  If pin 9 not connected to ground, verbose output for Arduino Serial Monitor is enabled. This is not suitable for Arduino Plotter.
 *
 *  Stored and displayed ESR is the average of the ESR's of the last storage period (1 min).
 *
 *  Data is stored to EEPROM in a delta format, starting with 16 bit start value
 *  adding an 8 bit signed delta for each storage period.
 *
 *  Storage time is 5 hours and 36 min (336 + initial sample) for one sample every minute.
 *  When EEPROM space is exhausted, data is compressed by combining 2 deltas,
 *  resulting in an effective 2 minutes storage period time, thus reducing the resolution.
 *  With 2 minutes per storage period, total storage time is 11h 12min. For a Li-ion this is equivalent to around 3300 mAh at a default load resistor of 2 + 1 Ohm.
 *  With 4 minutes per storage period, total storage time is 22h 24min.
 *
 *  One EEPROM block contains the initial start voltage, current value as well as the capacity, battery type and value of the used load resistor.
 *  These values are stored at the beginning of the measurement
 *  The capacity is stored at end of measurement or on button press during the storage.
 *
 *  LOGGER:
 *  Logger resistor is 0.2 Ohm and much smaller than the resistor used for ESR measurement.
 *  This is because this resistance is added to the ESR of the probe and may influence e.g. charging or discharging end detection of the external circuit.
 *  The current and voltage is sampled 769 times per second.
 *  Displayed and stored voltage is average of all samples, but for future use maximum and minimum are also available.
 *  If voltage or current is available logging starts.
 *  Both values are written to EEPROM. Zero ESR value is written too, but is not displayed in logger mode.
 *
 *
 *  Copyright (C) 2021-2026  Armin Joachimsmeyer
 *  armin.joachimsmeyer@gmail.com
 *
 *  https://github.com/ArminJo/Ultimate-Battery-Tester
 *
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
 */

#include <Arduino.h>

#include "pitches.h"

#define VERSION_EXAMPLE "7.2"
// The change log is at the bottom of the file

//#define TRACE
//#define DEBUG

//#define NO_TONE_WARNING_FOR_VOLTAGE_TOO_LOW_FOR_STANDARD_CAPACITY_COMPUTATION

/*
 * If you want, you can calibrate your ADC readout by replacing this value with the voltage you measured a the AREF pin after the program started.
 * For my Nanos I measured e.g. 1060 mV and 1093 mV.
 */
#if !defined(ADC_INTERNAL_REFERENCE_MILLIVOLT)
#define ADC_INTERNAL_REFERENCE_MILLIVOLT    1100 // Change to value measured at the AREF pin. If value > real AREF voltage, measured values are > real values
#endif
/*
 * Correct displayed voltage to be equal voltage at terminal for every range separately.
 * !!! Can be done only at stopped measurement, otherwise we likely measure externally also the voltage increase during the no-load period !!!
 * Not required for my version using 1% resistors.
 * Changing values currently only available for BD version!
 */
//#define SUPPORT_VOLTAGE_CORRECTION // ~350 bytes
/*
 * In WOKWI, we cannot simulate voltage division with resistors, so me must tweak it
 */
//#define IN_WOKWI
/*
 * Enables output of values and the discharge graph on a tablet or mobile running the BlueDisplay app.
 * Disables many Serial output to save program memory space.
 */
//#define SUPPORT_BLUEDISPLAY_CHART
#if defined(SUPPORT_BLUEDISPLAY_CHART)
// This requires 1304 bytes program memory and exceeds 100% in Arduino IDE, because the "-mrelax" linker option is not set there.
//#define ENABLE_DISPLAY_OF_DATE_AND_TIME
#endif

//
/*
 * Choose the type of LCD you use
 * Default is parallel LCD with 2 rows of 16 characters (1602).
 * 2004 Display is and will not be supported. Use BlueDisplay app instead.
 * Serial LCD uses A4/A5 - the hardware I2C pins on Arduino
 */
//#define USE_PARALLEL_1602_LCD // Is default and set by LCDPrintUtils.hpp
//#define USE_SERIAL_1602_LCD
//#define USE_NO_LCD
#if !defined(USE_NO_LCD)
#define USE_LCD
#include "LCDPrintUtils.hpp" // sets USE_PARALLEL_LCD or USE_SERIAL_LCD
#  if defined(USE_SERIAL_LCD)
#define USE_SOFT_I2C_MASTER // Requires SoftI2CMaster.h + SoftI2CMasterConfig.h. Saves 2110 bytes program memory and 200 bytes RAM compared with Arduino Wire
#include "LiquidCrystal_I2C.hpp"  // This defines USE_SOFT_I2C_MASTER, if SoftI2CMasterConfig.h is available. Use only the modified version delivered with this program!
LiquidCrystal_I2C myLCD(0x27, LCD_COLUMNS, LCD_ROWS);  // set the LCD address to 0x27 for a 16 chars and 2 line display
#  else
#include "LiquidCrystal.h"
//LiquidCrystal myLCD(2, 3, 4, 5, 6, 7);
//LiquidCrystal myLCD(7, 8, A0, A1, A2, A3);
LiquidCrystal myLCD(7, 8, 3, 4, 5, 6);
#  endif
#endif //!defined(USE_NO_LCD)
#define LCD_MESSAGE_PERSIST_TIME_MILLIS     2000 // 2 second to view a message on LCD - is also used in delayAndCheckForButtonPress()

/*
 * Pin and ADC definitions
 *
 * Pin 2 / INT0 is used for Start/Stop button
 * Pin 3 to 8 are used for parallel LCD connection
 * Pins A1 to A5 are used as digital outputs for range and load switching (and buzzer)
 */
#define ADC_CHANNEL_FOR_VOLTAGE          0 // Pin A0 / PC0 for Uno. This is the ADC channel, not the pin for voltage measurement!
// the next Analog pins are used as digital outputs for range and load switching (and buzzer)
#define VOLTAGE_RANGE_EXTENSION_1_PIN   A1 // PC1 This pin is low to extend the voltage range from 2.2 volt to 4.4 volt
#define VOLTAGE_RANGE_EXTENSION_2_PIN   A2 // PC2 This pin is low to extend the voltage range from 2.2 volt to 17.6 volt
#define VOLTAGE_RANGE_EXTENSION_3_PIN   A3 // PC3 This pin is low to extend the voltage range from 2.2 volt to 64.9 volt
#define ADC_CHANNEL_CURRENT                     6 // Pin A6 for Nano. This is the ADC channel, not the pin for current measurement!
#define ADC_CHANNEL_LOGGER_CURRENT              7 // Pin A7 for Nano. This is the ADC channel, not the pin for current measurement for Logger!
#define HIGHEST_ASSEMBLED_VOLTAGE_RANGE_MASK    0x08 // A3 - This pin must be actually assembled with a resistor
#define HIGHEST_ASSEMBLED_VOLTAGE_RANGE         3 // Channel
#define LOWEST_VOLTAGE_RANGE_PORT_MASK_DUMMY    0x01 // Mask for PC0! not applied to hardware.
#define VOLTAGE_RANGE_PORT_MASK                 0xE0 // PC1 to PC3

#if defined(USE_SERIAL_LCD)
// A4 + A5, the hardware I2C pins on Arduino, are used for Serial LCD, so we must redefine this 2 pins
#define LOAD_HIGH_PIN                           4 // This pin is high to switch on the high load (3 ohm)
#define BUZZER_PIN                              3
#define BUZZER_PIN_MASK                         0 // no Buzzer at Analog pins
#define OTHER_OUTPUTS_PIN_MASK                  0 // Alternate functions for Pin 4 + 5
#else
// Parallel LCD here
#define LOAD_HIGH_PIN                           A4 // PC4 This pin is high to switch on the high load (3 ohm)
#define LOAD_HIGH_PIN_MASK                      0x10 // Output PC4
#define BUZZER_PIN                              A5 // PC5
#define BUZZER_PIN_MASK                         0x20 // Output PC4
#define OTHER_OUTPUTS_PIN_MASK                  (LOAD_HIGH_PIN_MASK | BUZZER_PIN_MASK)
#endif // defined(USE_SERIAL_LCD)

// Mode pins
#define ONLY_PLOTTER_OUTPUT_PIN      9 // Verbose output to Arduino Serial Monitor is disabled, if connected to ground. This is intended for Arduino Plotter mode.
#define ONLY_LOGGER_MODE_PIN        10 // If connected to ground, current is measured at the shunt at channel 4 / A4 and voltage still at channel 0 / pin A0.
#define CUTOFF_LEVEL_PIN            11 // If connected to ground, CUTOFF_LEVEL_LOW is taken as startup default if no battery is inserted at startup.
#define LOAD_LOW_PIN                12 // This pin is high to switch on the low load (10 ohm). A4 is occupied by I2C for serial LCD display.
bool sLastValueOfCutoffLevelPin; // To support prints and voltage setting at changing between normal and low by using pin CUTOFF_LEVEL_PIN

/*
 * External circuit definitions
 */
#if !defined(LOGGER_SHUNT_RESISTOR_MILLIOHM)
#define LOGGER_SHUNT_RESISTOR_MILLIOHM          200    // 0.2 ohm -> Resolution of 5 mA, but we display the average of 769 values per second
#endif
#if !defined(ESR_SHUNT_RESISTOR_MILLIOHM)
#define ESR_SHUNT_RESISTOR_MILLIOHM             2000   // 2 ohm
#endif
#define LOAD_LOW_MILLIOHM                       (1000 + ESR_SHUNT_RESISTOR_MILLIOHM) // Additional 1 ohm
#define LOAD_HIGH_MILLIOHM                      (10 * 1000 + ESR_SHUNT_RESISTOR_MILLIOHM) // Additional 10 ohm
#define ATTENUATION_FACTOR_VOLTAGE_RANGE_0      2      // Divider with 100 kOhm and 100 kOhm -> 2.2 V range
#define ATTENUATION_FACTOR_VOLTAGE_RANGE_1      4      // Divider with 100 kOhm and 33.333 kOhm -> 4.4 V range
#define ATTENUATION_FACTOR_VOLTAGE_RANGE_2      16     // Divider with 100 kOhm and 6.666 kOhm -> 17.6 V range
#define ATTENUATION_FACTOR_VOLTAGE_RANGE_3      59     // Divider with 100 kOhm and 1.7 kOhm -> 64.9 V range - 59 to avoid 16 bit overflow for ...Millivolt
#if defined(SUPPORT_VOLTAGE_CORRECTION)
#define NUMBER_OF_CORRECTED_VOLTAGE_RANGES      (HIGHEST_ASSEMBLED_VOLTAGE_RANGE + 1) // 4
#else
#define NUMBER_OF_CORRECTED_VOLTAGE_RANGES      0
#endif
uint8_t const sVoltageAttenuationFactorArray[HIGHEST_ASSEMBLED_VOLTAGE_RANGE + 1] = { ATTENUATION_FACTOR_VOLTAGE_RANGE_0,
ATTENUATION_FACTOR_VOLTAGE_RANGE_1, ATTENUATION_FACTOR_VOLTAGE_RANGE_2, ATTENUATION_FACTOR_VOLTAGE_RANGE_3 };

/*
 * Imports and definitions for start/stop button at pin 2
 */
#define USE_BUTTON_0                // Enable code for button 0 at INT0 / pin 2.
#define NO_BUTTON_RELEASE_CALLBACK
//#define BUTTON_IS_ACTIVE_HIGH     // If you have an active high button (sensor button) attached
#include "EasyButtonAtInt01.hpp"
void handleStartStopButtonPress(bool aButtonToggleState);       // The button press callback function
EasyButton startStopButton0AtPin2(&handleStartStopButtonPress); // Button is connected to INT0 (pin2)
void checkForDelayedButtorProcessing(); // If LCD is in use do not process button
volatile bool sInLCDPrint;              // To synchronize LCD access for button handler
bool sOnlyPlotterOutput; // Suppress all serial output except logger data. Contains the (inverted) value of the pin ONLY_PLOTTER_OUTPUT_PIN

/*
 * Cutoff level
 */
#define CUTOFF_LEVEL_HIGH       0 // Switch off current percentage is 50% (shift 1 right) for logger. Is default case
#define CUTOFF_LEVEL_LOW        1 // 25% (shift 2 right) for logger.
#define CUTOFF_LEVEL_ZERO       2 // 12% (shift 3 right) for logger.

/*********************
 * Measurement timing
 *********************/
//#define TEST // to speed up testing the code
#if defined(TEST)
#define NUMBER_OF_INITIAL_SAMPLES               4 // 4 seconds (-2 for initial display of append message) before starting discharge and storing, to have time to just test for ESR of battery.
#define SAMPLE_PERIOD_OF_LOAD_ACIVATED_MILLIS   500 // The time of the activated load for one sample.
#define INITIAL_NUMBER_OF_SECONDS_PER_STORAGE   5 // 1 minute, if we have 1 sample per second
#else
#define NUMBER_OF_INITIAL_SAMPLES               30 // Before starting discharge and storing, to have time to just test for ESR of battery. 30 seconds with SAMPLE_PERIOD_OF_LOAD_ACIVATED_MILLIS as 1000.
#define SAMPLE_PERIOD_OF_LOAD_ACIVATED_MILLIS   MILLIS_IN_ONE_SECOND // 1 s. The duration of one sample period / The time of the activated load for one sample period.
/*
 * Using minutes instead of seconds and avoiding the divide by 60 at many places increases code size by 46 bytes :-(
 */
#  if !defined(INITIAL_NUMBER_OF_SECONDS_PER_STORAGE)
#define INITIAL_NUMBER_OF_SECONDS_PER_STORAGE   SECONDS_IN_ONE_MINUTE // 60, if we have 1 sample per second (SAMPLE_PERIOD_OF_LOAD_ACIVATED_MILLIS)
#  endif
#endif

/*
 * For Logger current, we take the average of 20 ms (50 HZ) | 769 samples to cover variations due to mains frequency
 * and 1 voltage value.
 * This is done 20 times per second and then averaged again.
 */
#define LOGGER_NUMBER_OF_SAMPLES_PER_MEASUREMENT 769 // for ADC_PRESCALE32 and 20 ms (50 Hz)
#define LOGGER_SAMPLE_PERIOD_MILLIS             50 // 20 Hz.
#define LOGGER_SAMPLE_FREQUENCY_HZ              (MILLIS_IN_ONE_SECOND / LOGGER_SAMPLE_PERIOD_MILLIS) // 20 Hz

#define MAX_VALUES_DISPLAYED_IN_PLOTTER         500 // The Arduino 1.8 Plotter displays 500 values before scrolling
#define BATTERY_OR_VOLTAGE_DETECTION_PERIOD_MILLIS         (MILLIS_IN_ONE_SECOND / 2) // 500 ms

/*******************
 * Attention timing
 *******************/
#define STATE_BATTERY_DETECTION_ATTENTION_PERIOD_MILLIS     (MILLIS_IN_ONE_SECOND * SECONDS_IN_ONE_MINUTE) // 60000 fits in uint16_t
#define STATE_STOP_ATTENTION_PERIOD_MILLIS                  ((uint32_t)MILLIS_IN_ONE_SECOND * SECONDS_IN_ONE_MINUTE * 10)

/************************
 * Tester state machine
 ***********************/
#define STATE_SETUP_AND_READ_EEPROM          0 // "Booting"
#define STATE_WAITING_FOR_BATTERY_OR_EXTERNAL 1 // "Waiting" Check if battery is inserted and determine type or external current or voltage is connected to start with logging
#define STATE_INITIAL_SAMPLES                2 // "Testing" Only voltage (and ESR) measurement every n seconds for NUMBER_OF_INITIAL_SAMPLES samples
#define STATE_SAMPLE_AND_STORE_TO_EEPROM     3 // "Running" Main measurement state, get values and store to EEPROM
#define STATE_STOPPED                        4 // "Stopped" / "Finished" Switch off voltage reached, until removal of battery

/***************************
 * Support for BlueDisplay
 ***************************/
#if defined (DOXYGEN)
#define SUPPORT_BLUEDISPLAY_CHART // always document it :-)
#endif
#if defined(SUPPORT_BLUEDISPLAY_CHART)
//#define DO_NOT_NEED_BASIC_TOUCH_EVENTS
#define DO_NOT_NEED_LONG_TOUCH_DOWN_AND_SWIPE_EVENTS  // Disables LongTouchDown and SwipeEnd events.
#define DO_NOT_NEED_SPEAK_EVENTS            // Disables SpeakingDone event handling. Saves up to 54 bytes program memory and 18 bytes RAM.
#define ONLY_CONNECT_EVENT_REQUIRED         // Disables reorientation, redraw and SensorChange events
#define SUPPRESS_SERIAL_PRINT               // To reduce code size
#  if !defined(ALLOW_SERIAL_PRINT_STOP_CONDITION)
#define SUPPRESS_SERIAL_PRINT_STOP_CONDITION // To reduce code size
#  endif
#  if !defined(ALLOW_SERIAL_PRINT_FOUND_REMOVING_CONDITION)
//#define SUPPRESS_SERIAL_PRINT_FOUND_REMOVING_CONDITION // To reduce code size. - not required yet
#  endif
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
void loop() {
#if defined(SUPPORT_BLUEDISPLAY_CHART)
    checkAndHandleEvents();
#endif
    checkAndHandleVCCUndervoltage();

    if (sTesterInfo.MeasurementState == STATE_WAITING_FOR_BATTERY_OR_EXTERNAL) {
        handlePeriodicDetectionOfProbe();
    } else {
        /*
         * STATE_INITIAL_SAMPLES / Testing or STATE_SAMPLE_AND_STORE_TO_EEPROM / Running or STATE_STOPPED here
         */
        if (sTesterInfo.inLoggerModeAndFlags) {
            getPeriodicAccumulatingLoggerValues();
        }
        auto tMillis = millis();
        auto tTimeDifference = tMillis - sTesterInfo.LastMillisOfSample; // compute with full 32 bit -
        // For discharging, add LoadSwitchSettleTimeMillis to the second condition
        if ((sTesterInfo.inLoggerModeAndFlags && sLogger1SecondAccumulator.RawSampleCount == LOGGER_SAMPLE_FREQUENCY_HZ)
                || (!sTesterInfo.inLoggerModeAndFlags && (uint16_t) tTimeDifference // - and compare only 16 bit values, because it cannot exceed 1 second much
                >= (SAMPLE_PERIOD_OF_LOAD_ACIVATED_MILLIS + sCurrentBatteryTypeInfo.LoadSwitchSettleTimeMillis))) {
            /*
             * Here sample period of one second expired.
             * The first period after switching to this states is undetermined, because LastMillisOfSample is undetermined
             * sTesterInfo.MeasurementState is STATE_INITIAL_SAMPLES or STATE_SAMPLE_AND_STORE_TO_EEPROM or STATE_STOPPED
             * Do all this every second (of battery load)
             */
            sTesterInfo.LastMillisOfSample = tMillis;

            /*
             * Get values
             */
            if (sTesterInfo.inLoggerModeAndFlags) {
                getLogger1SecondValues();
            } else {
                getBatteryValues();
            }

            if (sTesterInfo.MeasurementState == STATE_STOPPED) {
                // Print only tVoltageNoLoadMillivolt and check for periodic attention
                handleStateStoppedLCD_BD();
            } else {
                /*
                 * STATE_INITIAL_SAMPLES or STATE_SAMPLE_AND_STORE_TO_EEPROM here
                 * Check removed battery in STATE_INITIAL_SAMPLES
                 * else display values
                 */
                if (sTesterInfo.MeasurementState == STATE_INITIAL_SAMPLES) {
                    detectVoltageOrCurrentRemoved();
                }
                // check again for not removing detected
                if (sTesterInfo.MeasurementState != STATE_WAITING_FOR_BATTERY_OR_EXTERNAL) {
                    // Here no removing detected -> add current to capacity and print measurement values
                    addToCapacity();
                    printMeasurementValuesLCD_BD();
                }
                /*
                 * Check for end of STATE_INITIAL_SAMPLES
                 */
                if (sTesterInfo.MeasurementState == STATE_INITIAL_SAMPLES && sTesterInfo.NumbersOfInitialSamplesToGo == 0) {
                    handleEndOfStateInitialSamples();
                }

                if (sTesterInfo.MeasurementState == STATE_SAMPLE_AND_STORE_TO_EEPROM) {
                    /*
                     * STORE to EEPROM
                     */
                    handlePeriodicStoringToEEPROM(); // also calls checkAndHandleStopConditionLCD() after storing
                }
            }
        }
    } // end of handling each second

    if (!sTesterInfo.inLoggerModeAndFlags) {
#if defined(SUPPORT_BLUEDISPLAY_CHART)
        delayMillisAndCheckForEvent(100);
#else
        delay(100);
#endif

        getOnlyPlotterOutputPinLevel();
    }

    checkAndHandleCutoffPinLevelChange();

} // end of loop()

/*
 * Check for plotter mode pin change
 * Is not really required for logger and sets reference to default,
 * which requires additional 8 ms for logger to switch back to 4.4 V range
 */
void getOnlyPlotterOutputPinLevel() {
    sOnlyPlotterOutput = !digitalRead(ONLY_PLOTTER_OUTPUT_PIN);
}

/*
 * Check for VCC undervoltage during measurements
 * isVCCUndervoltageMultipleTimes() checks VCC only every 10 seconds
 */
void checkAndHandleVCCUndervoltage() {
    if (sTesterInfo.MeasurementState != STATE_STOPPED && isVCCUndervoltageMultipleTimes()) {
#if defined(USE_LCD)
        myLCD.setCursor(0, 1);
        myLCD.print(F("VCC undervoltage"));
        myLCD.setCursor(7, 0);
        myLCD.print(F("VCC="));
        myLCD.print(getVCCVoltage(), 2);
        myLCD.print('V');
#endif
        playEndTone(); // 3 seconds
        switchToStateStopped('U');
    }
    /*
     * Reset ADC reference source to internal 1.1 V
     */
    checkAndWaitForReferenceAndChannelToSwitch(ADC_CHANNEL_CURRENT, INTERNAL);
}

/*
 * Check if battery was inserted or voltage connected.
 * If yes, show values and type detected, update cutoff values and switch to state STATE_INITIAL_SAMPLES.
 *      Once after boot print "dbl press = stop" and "Press button to append to EEPROM".
 *
 * If no, print VCC voltage, but not if voltage was detected or battery was inserted before,
 *      to not overwrite battery/logger voltage printed in state STATE_INITIAL_SAMPLES.
 * Check for attention every minute.
 */
void handlePeriodicDetectionOfProbe() {
    auto tTimeDifference = millis() - sTesterInfo.LastMillisOfBatteryOrVoltageDetection; // compute with full 32 bit -
    if ((uint16_t) tTimeDifference >= BATTERY_OR_VOLTAGE_DETECTION_PERIOD_MILLIS) { // - and compare only 16 bit values
        // initial delay introduced by truncating to 16 bit is not critical here :-)
        sTesterInfo.LastMillisOfBatteryOrVoltageDetection = millis();

        /*
         * Check if battery was inserted or voltage connected
         */
        setLoad(NO_LOAD);
        bool tBatteryOrCurrentOrVoltageWasDetected = detectBatteryOrLoggerVoltageOrCurrentLCD_BD();
        // we waited up to 2 seconds in detectBatteryOrLoggerVoltageOrCurrentLCD_BD(), so must check if mode has not changed by button press
        if (sTesterInfo.MeasurementState == STATE_WAITING_FOR_BATTERY_OR_EXTERNAL) {
            if (tBatteryOrCurrentOrVoltageWasDetected) {
                /*
                 * Successfully detected here -> switch state and show values detected
                 */
                switchToStateInitialSamples();

#if !defined(SUPPORT_BLUEDISPLAY_CHART)
                // If found, print button usage once at start of InitialESRMeasurement, but not, if display is attached, which has attach button
                if (!sTesterInfo.ButtonUsageMessageWasPrinted) {
                    printButtonUsageMessageLCD();
                    sTesterInfo.ButtonUsageMessageWasPrinted = true;
                    sTesterInfo.VoltageNoLoadIsDisplayedOnLCD = false;
                }
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

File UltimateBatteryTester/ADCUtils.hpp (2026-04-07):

/*
 * ADCUtils.hpp
 *
 * ADC utility functions. Conversion time is defined as 0.104 milliseconds for 16 MHz Arduinos in ADCUtils.h.
 *
 *  Copyright (C) 2016-2023  Armin Joachimsmeyer
 *  Email: armin.joachimsmeyer@gmail.com
 *
 *  This file is part of Arduino-Utils https://github.com/ArminJo/Arduino-Utils.
 *
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
 *  You should have received a copy of the GNU General Public License
 *  along with this program. If not, see <http://www.gnu.org/licenses/gpl.html>.
 */

#ifndef _ADC_UTILS_HPP
#define _ADC_UTILS_HPP

#include "ADCUtils.h"
#if defined(ADC_UTILS_ARE_AVAILABLE) // set in ADCUtils.h, if supported architecture was detected
#define ADC_UTILS_ARE_INCLUDED

// Helper macro for getting a macro definition as string
#if !defined(STR_HELPER) && !defined(STR)
#define STR_HELPER(x) #x
#define STR(x) STR_HELPER(x)
#endif
#if !defined(BITS_PER_BYTE)
#define BITS_PER_BYTE 8
#endif

/*
 * By replacing this value with the voltage you measured a the AREF pin after a conversion
 * with INTERNAL you can calibrate your ADC readout. For my Nanos I measured e.g. 1060 mV and 1093 mV.
 * If value > real AREF voltage, measured values are > real values
 */
#if !defined(ADC_INTERNAL_REFERENCE_MILLIVOLT)
#define ADC_INTERNAL_REFERENCE_MILLIVOLT    1100 // Change to value measured at the AREF pin.
#endif

// Union to speed up the combination of low and high bytes to a word
// it is not optimal since the compiler still generates 2 unnecessary moves
// but using  -- value = (high << 8) | low -- gives 5 unnecessary instructions
union WordUnionForADCUtils {
    struct {
        uint8_t LowByte;
        uint8_t HighByte;
    } UByte;
    uint16_t UWord;
    int16_t Word;
    uint8_t *BytePointer;
};

/*
 * Enable this to see information on each call.
 * Since there should be no library which uses Serial, it should only be enabled for development purposes.
 */
#if defined(DEBUG)
#define LOCAL_DEBUG
#else
//#define LOCAL_DEBUG // This enables debug output only for this file
#endif
#if defined(INFO)
#define LOCAL_INFO
#else
//#define LOCAL_INFO // This enables debug output only for this file
#endif

/*
 * Persistent storage for VCC value
 */
float sVCCVoltage;
uint16_t sVCCVoltageMillivolt;

// for isVCCTooLowMultipleTimes()
long sLastVCCCheckMillis;
uint8_t sVCCTooLowCounter = 0;

/*
 * Conversion time is defined as 0.104 milliseconds by ADC_PRESCALE in ADCUtils.h.
 * Use previous settings
 */
uint16_t readADCChannel() {
    WordUnionForADCUtils tUValue;

    // ADCSRB = 0; // Only active if ADATE is set to 1.
    // ADSC-StartConversion ADIF-Reset Interrupt Flag - NOT free running mode
    ADCSRA = (_BV(ADEN) | _BV(ADSC) | _BV(ADIF) | ADC_PRESCALE);

    // wait for single conversion to finish
    loop_until_bit_is_clear(ADCSRA, ADSC);

    // Get value
    tUValue.UByte.LowByte = ADCL;
    tUValue.UByte.HighByte = ADCH;
    return tUValue.UWord;
    //    return ADCL | (ADCH <<8); // needs 4 bytes more
}

/*
 * Use new channel aADCChannelNumber, but do not wait for channel switching
 */
uint16_t readADCChannel(uint8_t aADCChannelNumber) {
    WordUnionForADCUtils tUValue;
    ADMUX = aADCChannelNumber | (DEFAULT << SHIFT_VALUE_FOR_REFERENCE);

    // ADCSRB = 0; // Only active if ADATE is set to 1.
    // ADSC-StartConversion ADIF-Reset Interrupt Flag - NOT free running mode
    ADCSRA = (_BV(ADEN) | _BV(ADSC) | _BV(ADIF) | ADC_PRESCALE);

    // wait for single conversion to finish
    loop_until_bit_is_clear(ADCSRA, ADSC);

    // Get value
    tUValue.UByte.LowByte = ADCL;
    tUValue.UByte.HighByte = ADCH;
    return tUValue.UWord;
    //    return ADCL | (ADCH <<8); // needs 4 bytes more
}
/*
 * Conversion time is defined as 0.104 milliseconds by ADC_PRESCALE in ADCUtils.h.
 */
uint16_t readADCChannelWithReference(uint8_t aADCChannelNumber, uint8_t aReference) {
    WordUnionForADCUtils tUValue;
    ADMUX = aADCChannelNumber | (aReference << SHIFT_VALUE_FOR_REFERENCE);

    // ADCSRB = 0; // Only active if ADATE is set to 1.
    // ADSC-StartConversion ADIF-Reset Interrupt Flag - NOT free running mode
    ADCSRA = (_BV(ADEN) | _BV(ADSC) | _BV(ADIF) | ADC_PRESCALE);

    // wait for single conversion to finish
    loop_until_bit_is_clear(ADCSRA, ADSC);

    // Get value
    tUValue.UByte.LowByte = ADCL;
    tUValue.UByte.HighByte = ADCH;
    return tUValue.UWord;
}

uint16_t readADCChannelWithReferenceUsingInternalReference(uint8_t aADCChannelNumber) {
    WordUnionForADCUtils tUValue;
    ADMUX = aADCChannelNumber | (INTERNAL << SHIFT_VALUE_FOR_REFERENCE);

    // ADCSRB = 0; // Only active if ADATE is set to 1.
    // ADSC-StartConversion ADIF-Reset Interrupt Flag - NOT free running mode
    ADCSRA = (_BV(ADEN) | _BV(ADSC) | _BV(ADIF) | ADC_PRESCALE);

    // wait for single conversion to finish
    loop_until_bit_is_clear(ADCSRA, ADSC);

    // Get value
    tUValue.UByte.LowByte = ADCL;
    tUValue.UByte.HighByte = ADCH;
    return tUValue.UWord;
}
/*
 * Conversion time is defined as 0.104 milliseconds by ADC_PRESCALE in ADCUtils.h.
 * Does NOT restore ADMUX after reading
 */
uint16_t waitAndReadADCChannelWithReference(uint8_t aADCChannelNumber, uint8_t aReference) {
    checkAndWaitForReferenceAndChannelToSwitch(aADCChannelNumber, aReference);
    return readADCChannelWithReference(aADCChannelNumber, aReference);
}

/*
 * Conversion time is defined as 0.104 milliseconds by ADC_PRESCALE in ADCUtils.h.
 * Restores ADMUX after reading
 */
uint16_t waitAndReadADCChannelWithReferenceAndRestoreADMUXAndReference(uint8_t aADCChannelNumber, uint8_t aReference) {
    uint8_t tOldADMUX = checkAndWaitForReferenceAndChannelToSwitch(aADCChannelNumber, aReference);
    uint16_t tResult = readADCChannelWithReference(aADCChannelNumber, aReference);
    checkAndWaitForReferenceAndChannelToSwitch(tOldADMUX & MASK_FOR_ADC_CHANNELS, tOldADMUX >> SHIFT_VALUE_FOR_REFERENCE);
    return tResult;
}

/*
 * To prepare reference and ADMUX for next measurement
 */
void setADCChannelAndReferenceForNextConversion(uint8_t aADCChannelNumber, uint8_t aReference) {
    ADMUX = aADCChannelNumber | (aReference << SHIFT_VALUE_FOR_REFERENCE);
}

/*
 * 100 kOhm requires < 100 us, 1 MOhm requires 120 us S&H switching time
 */
void setADCChannelForNextConversionAndWaitUsingInternalReference(uint8_t aADCChannelNumber) {
    ADMUX = aADCChannelNumber | (INTERNAL << SHIFT_VALUE_FOR_REFERENCE);
    delayMicroseconds(120); // experimental value is <= 1100 us for Nano board
}

void setADCChannelForNextConversionAndWaitUsingDefaultReference(uint8_t aADCChannelNumber) {
    ADMUX = aADCChannelNumber | (DEFAULT << SHIFT_VALUE_FOR_REFERENCE);
    delayMicroseconds(120); // experimental value is <= 1100 us for Nano board
}
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

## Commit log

2022-02-18 Version 1.1
    [UltimateBatteryTester.fzz]
2022-03-23 use average of ESR
    [UltimateBatteryTester.fzz]
2022-08-01 Fixed bug for ESR > 64 Ohm
    [ADCUtils.hpp, UltimateBatteryTester.ino]
2022-09-21 Switch off voltage detection fixed
    [UltimateBatteryTester.ino]
2022-12-12 Added battery packs and documentation
2023-03-10 Output values bugs fixed
    [UltimateBatteryTester.ino]
2023-03-11 Fixed conversion does not clear rest of EEPROM bug
    [UltimateBatteryTester.ino]
2023-11-20 BUTTON_IS_ACTIVE_HIGH is not default any more
2023-11-22 If powered by USB plotter pin logic is reversed, i.e. plotter output is enabled if NOT connected to ground
    [ADCUtils.hpp, UltimateBatteryTester.ino]
2023-11-25 Fix bug for appending to compressed data. Minor improvements.
    [UltimateBatteryTester.ino]
2023-11-28 Print also capacity at SwitchOffVoltageMillivolt if SwitchOffVoltageMillivoltLow was used.
2023-12-13 In state detecting battery, you can toggle cutoff voltage between high, low and zero (0.1 V) with stop button
2023-12-13 Synchronizing of LCD access for button handler, avoiding corrupted display content
    [UltimateBatteryTester.ino]
2023-12-26 In state detecting battery, you can toggle cutoff voltage between high, low and zero (50 mV) with stop button
2023-12-30 Use capacity between NominalFullVoltageMillivolt and SwitchOffVoltageMillivoltHigh as standard capacity. Support for storage period of 120 s.
2024-01-01 Standard capacity computed.
    [UltimateBatteryTester.fzz]
2024-03-12 Fixed displayed values after battery detection
    [UltimateBatteryTester.ino]
2025-03-21 Logger improved
    [UltimateBatteryTester.fzz]
2025-09-08 Miscellaneous improvements and zero voltage per battery type
2025-10-08 Version 7.0 beta - Changed analog pin assignments for two additional voltage ranges using internal reference.
2025-10-09 reset sample timing for first sample
    [UltimateBatteryTester.ino]
2025-10-14 Fixed some bugs in logger mode.
    [UltimateBatteryTester.ino]
2026-02-05 First tap on Brightness button only makes refresh.
2026-02-11 Detection if powered by USB removed to save space
2026-02-28 Fixed overflow bug relevant after 336 storage periods. Fixed bugs in ESR and load resistor computations. Bumped version to 7.1.0
    [UltimateBatteryTester.ino]
2026-03-05 Bumped version to 7.2.0 - BatteryTypeInfoArray now in FLASH memory
2026-03-09 No temporary disconnection of the load for Power Bank. The load value is always displayed. Fixed missing display of periods 56 to 67.
    [UltimateBatteryTester.ino]
2026-04-07 Added optional SUPPORT_VOLTAGE_CORRECTION and VoltageAttenuationFactorCorrectionArray.

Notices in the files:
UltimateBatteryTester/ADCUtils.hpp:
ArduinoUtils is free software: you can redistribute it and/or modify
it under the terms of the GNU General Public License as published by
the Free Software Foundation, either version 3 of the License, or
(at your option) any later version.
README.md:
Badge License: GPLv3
